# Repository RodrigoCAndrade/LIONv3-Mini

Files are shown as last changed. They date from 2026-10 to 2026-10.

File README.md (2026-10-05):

<div align="center">
  Rodrigo Andrade Logo
</div>

<h1 align="center">LIONv3-Mini Module</h1>

<p align="center">
    
    
    
    
    
</p>

<br>

<p align="center">
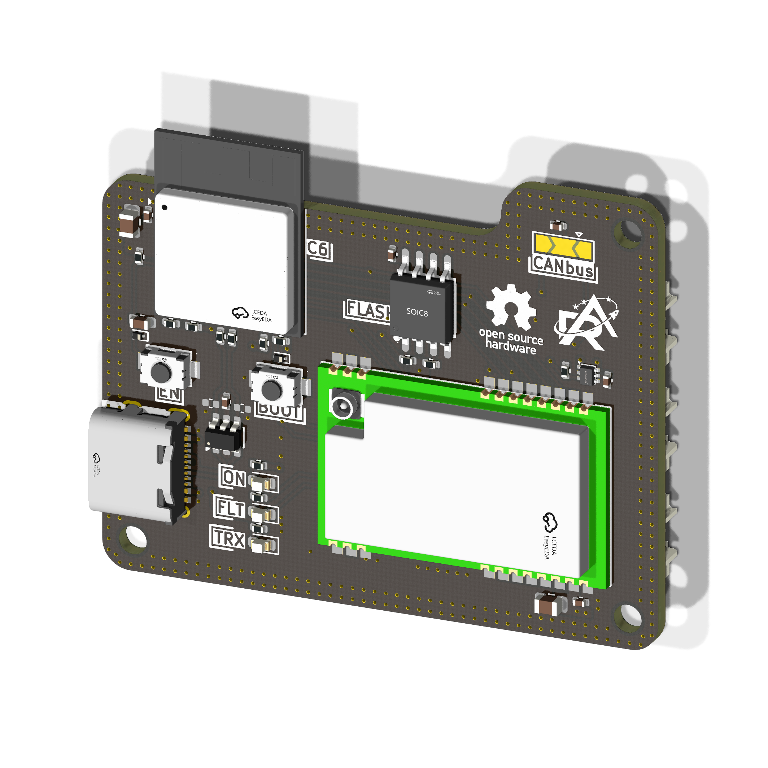
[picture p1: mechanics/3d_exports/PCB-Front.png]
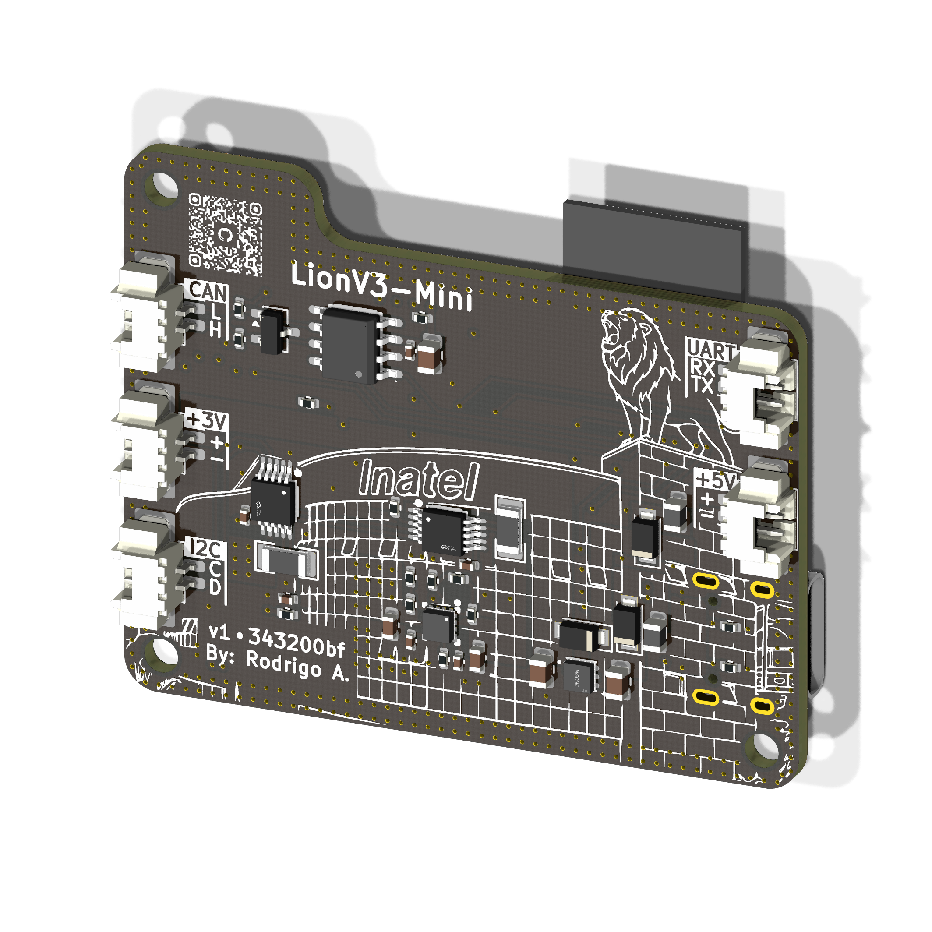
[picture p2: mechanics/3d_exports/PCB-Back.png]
    
</p>

## Overview

The LIONv3-Mini is a miniaturized version of the [LIONv3-R](https://github.com/RodrigoCAndrade/LIONv3-Mini), without an onboard LoRa PCB antenna. Built around the ESP32-C6 with 16 MB of external flash, it offers local connectivity over Wi-Fi, Zigbee and Thread, plus LoRa and LR-FHSS for reliable Direct-to-Satellite (DtS) or terrestrial uplinks from remote sites at higher device densities than conventional LoRa. It is a scalable platform for telemetry, global asset tracking and remote sensing.

## Repository Organization

* `docs`: Systems engineering documentation, including schematics, datasheets, requirements (SRD), interface control (ICD) and diagrams.
* `hardware`: Native KiCad project and manufacturing files.
* `mechanics`: 3D models, technical drawings, and physical integration constraints.
* `software`: Embedded firmware and support testing scripts.

## Releases

<table>
  <thead>
    <tr>
      <th>Render</th>
      <th>Hardware Revision</th>
      <th>Status</th>
      <th>Latest Release</th>
      <th>Date</th>
      <th>Datasheet</th>
      <th>BOM</th>
      <th>Manufacturing Info</th>
    </tr>
  </thead>
  <tbody>
    <tr>
      <td>board render</td>
      <td>LIONv3-Mini</td>
      <td>🚧 Development</td>
      <td><a href="#">-</a></td>
      <td>05-10-2026</td>
      <td><a href="#">PDF</a></td>
      <td><a href="hardware/Fabrication/BOM-LIONv3.csv">Available</a></td>
      <td><a href="hardware/Fabrication/GERBER-LIONv3.zip">Gerber</a></td>
    </tr>
  </tbody>
</table>

## Fabrication

This board is intended to be fabricated at [JLCPCB](https://jlcpcb.com/). The Gerber files, position files and BOM are available. For complete instructions, see the [Fabrication Guide](hardware/Fabrication/LIONv3-Mini%20Fabrication%20Guide.pdf). Please note that we do not guarantee the board will work, and any manufacturing issues are the user's responsibility. If you find an error or have suggestions for improvement, please do not hesitate to contribute.

## Contributing

We welcome contributions to this project! To ensure a smooth collaboration and maintain our engineering standards, please review our [Contribution Guidelines](CONTRIBUTING.md) before opening any issues, modifying the hardware design, or submitting pull requests.

## References

This board was developed from scratch, but draws on the earlier LIONv1 and LIONv2 designed by [Diego Anestor Coutinho](https://github.com/DIEGOVZK) and [Arielli Ajudarte](https://github.com/ari-aju). The v3 introduces several improvements:

- Dedicated low-power MCU on board
- LR-FHSS support and a more capable LoRa transceiver, covering both sub-GHz and S-band
- External flash for store-and-forward applications
- More compact form factor

<p align="center">
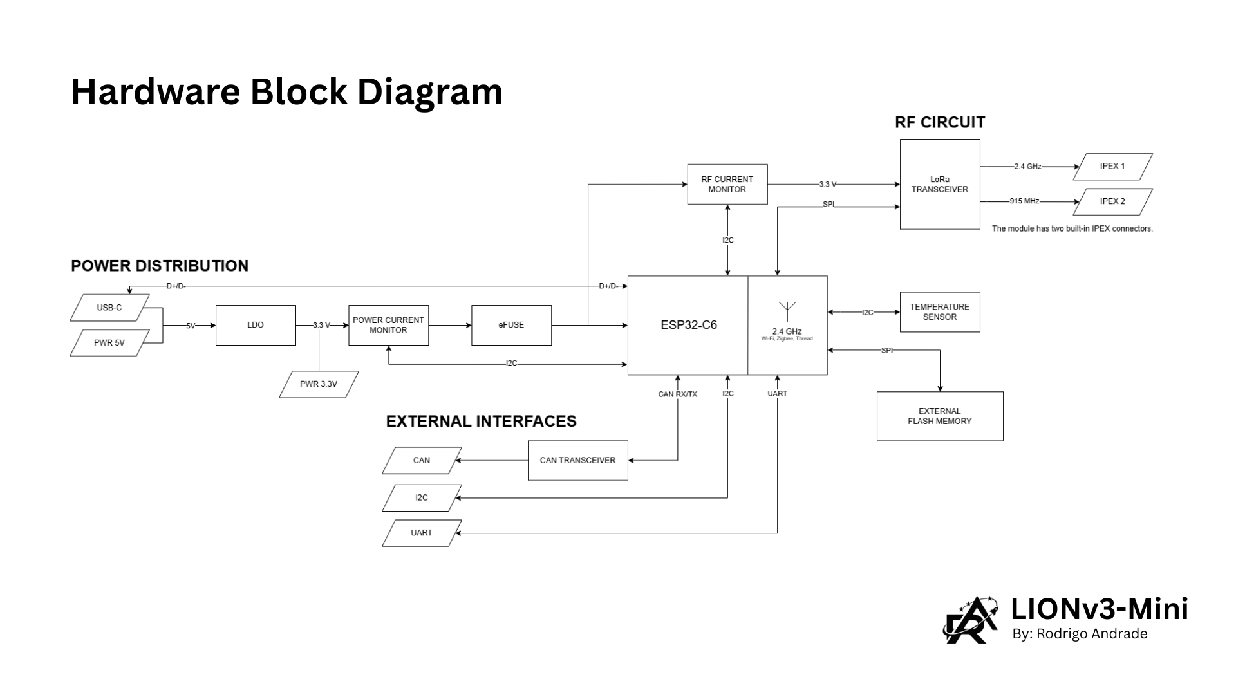
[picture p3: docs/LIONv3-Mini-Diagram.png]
    
</p>

## License

This project utilizes a dual-licensing approach to maximize flexibility and adoption:

* **Hardware:** The hardware designs and schematics are licensed under the permissive **[CERN-OHL-P-2.0](hardware/LICENSE)** open-hardware license. You are entirely free to use, modify, distribute, and commercialize the design without any copyleft obligations to share your derived works under the same terms.
* **Software:** All embedded firmware and utility scripts are licensed under the **[MIT License](software/LICENSE)**. You are free to use, modify, and distribute the code without restriction, provided the original copyright notice and permission notice are included.

## Acknowledgments

This work was carried out at the National Institute of Telecommunications (Inatel) with the support of three research laboratories. The EMBRAPII Inatel Competence Center for 5G and 6G Networks [(xGMobile)](https://inatel.br/xgmobile/) supported this project through its Talent Development Program (PFT xGMobile), alongside the Radio & Communication Laboratory [(RadioCom Lab)](https://inatel.br/radiocomlab/) and the Wireless and Artificial Intelligence Laboratory [(WAI Lab)](https://inatel.br/wailab/). Many thanks to the researchers and staff of all three laboratories for their help and for the infrastructure that made the LIONv3-Mini possible.

<p align="center">
  Funding
</p>

<p align="center">
  <sub>Built with ❤️ by <a href="https://rodrigoandrade.com">Rodrigo de Carvalho Andrade</a></sub>
</p>

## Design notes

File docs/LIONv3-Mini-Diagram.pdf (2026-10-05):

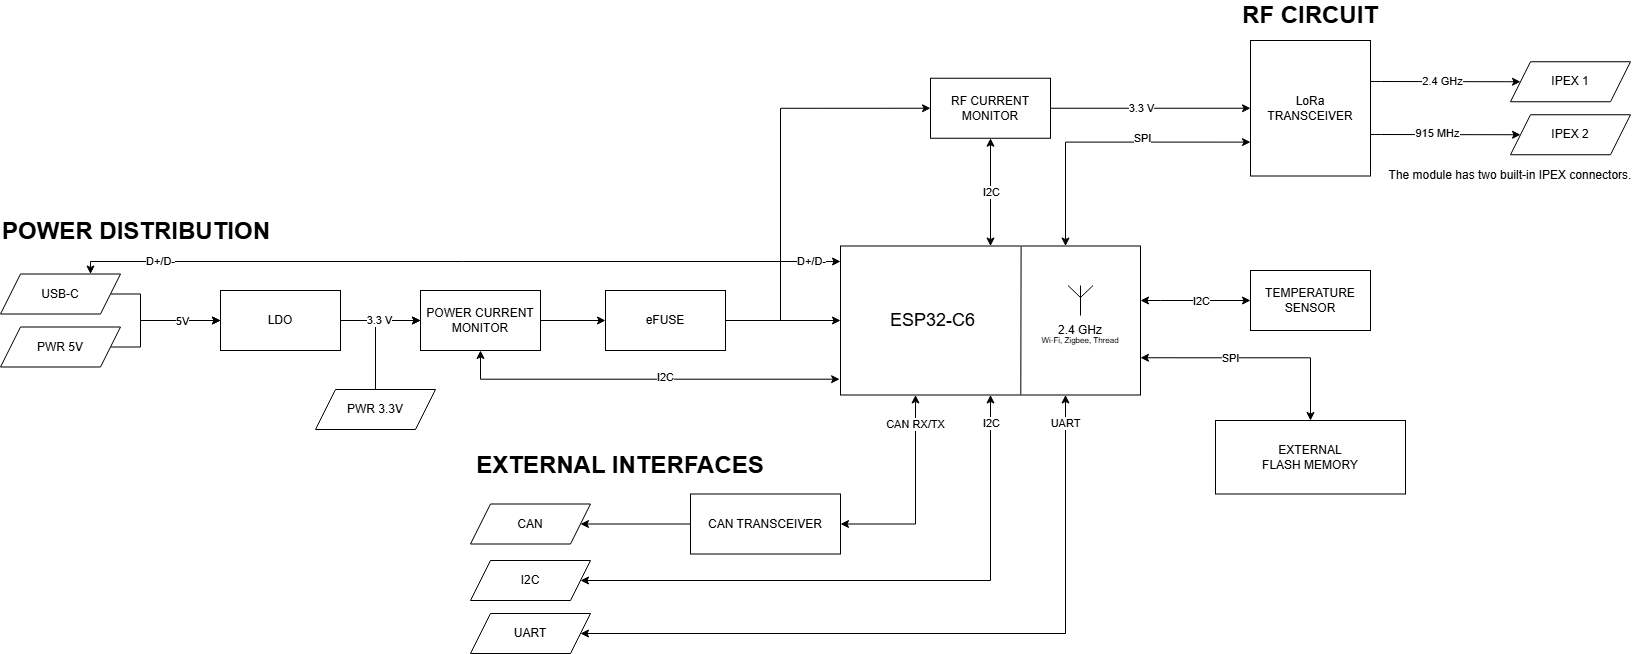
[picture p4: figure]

LIONv3-Mini

By: Rodrigo Andrade

Hardware Block Diagram

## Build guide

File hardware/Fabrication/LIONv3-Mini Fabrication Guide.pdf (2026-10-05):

# LIONv3-Mini Fabrication Guide

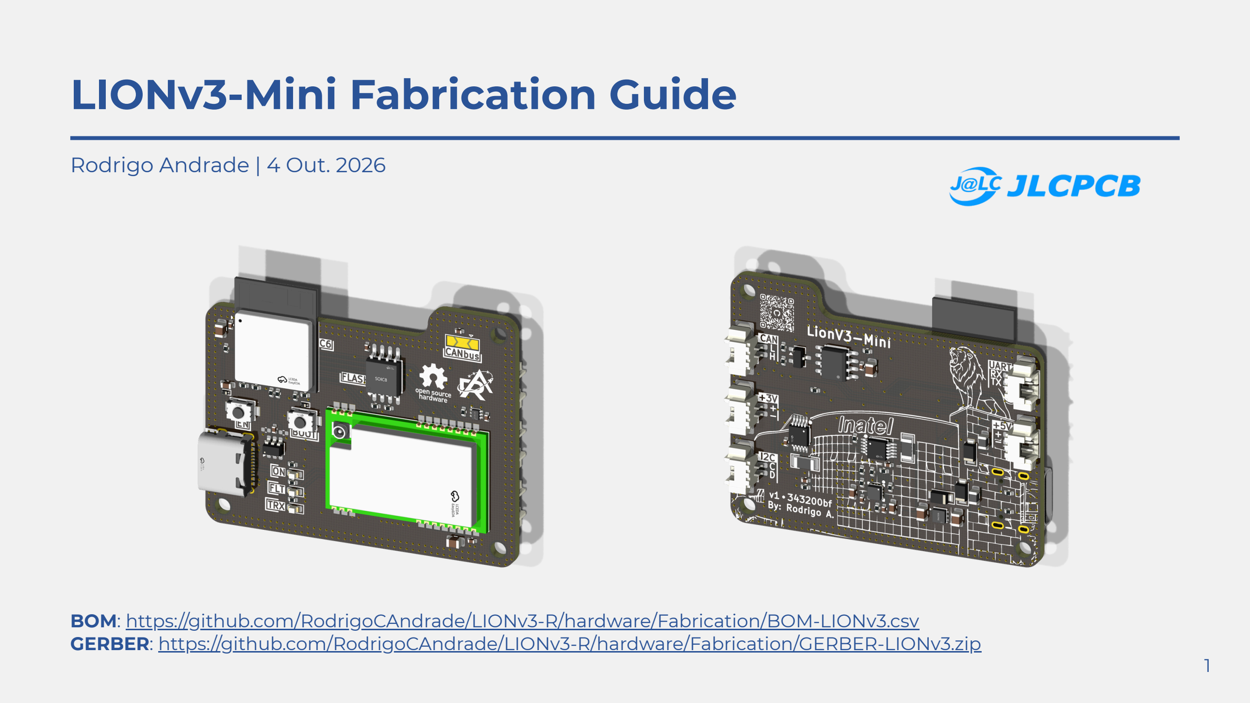
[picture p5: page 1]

Rodrigo Andrade | 4 Out. 2026

BOM: https://github.com/RodrigoCAndrade/LIONv3-R/hardware/Fabrication/BOM-LIONv3.csv GERBER: https://github.com/RodrigoCAndrade/LIONv3-R/hardware/Fabrication/GERBER-LIONv3.zip

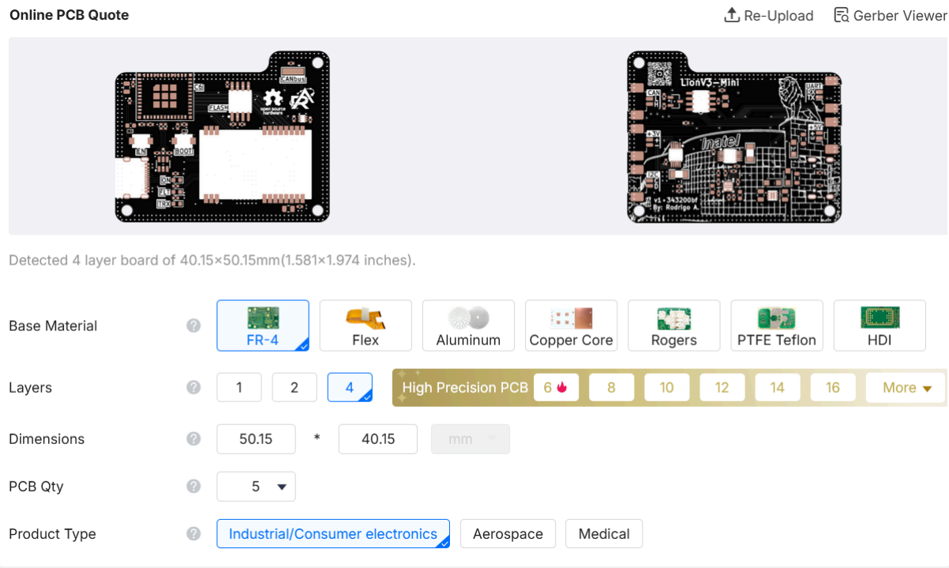
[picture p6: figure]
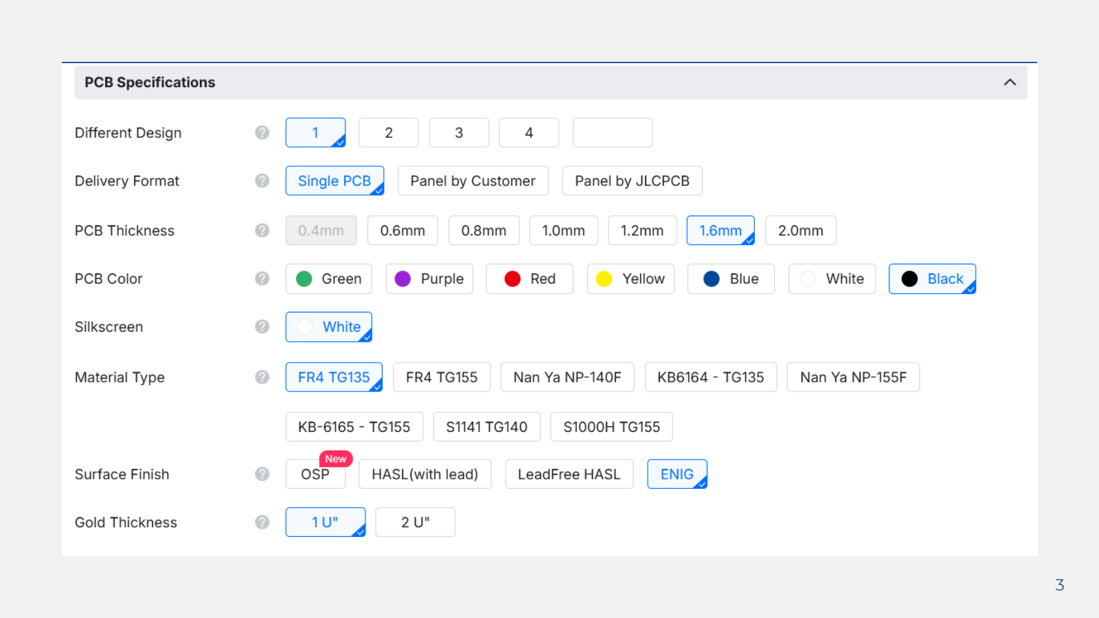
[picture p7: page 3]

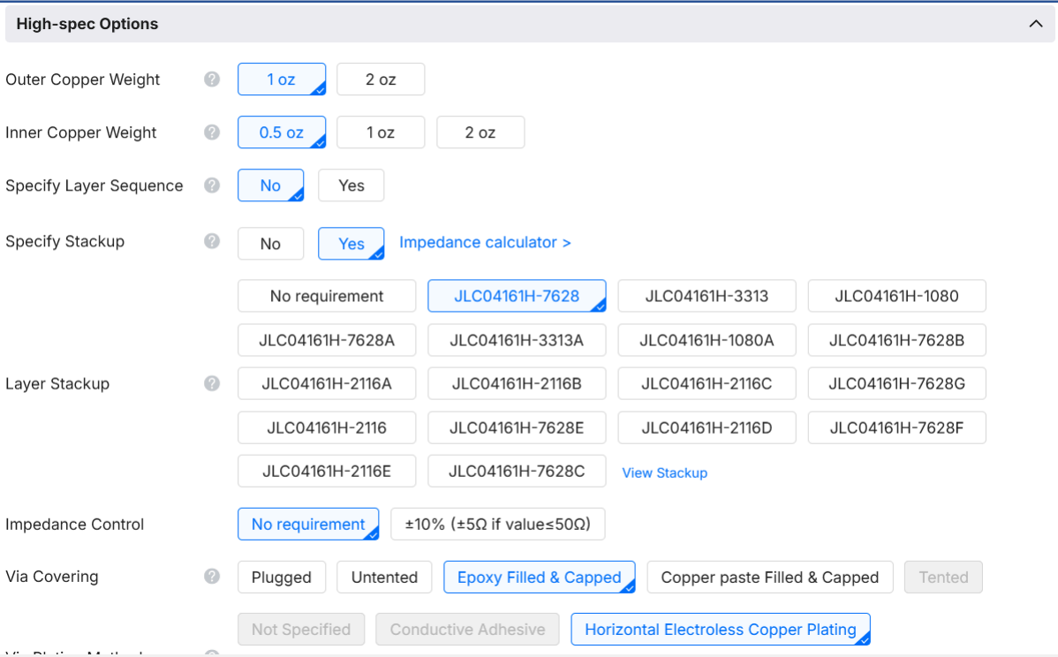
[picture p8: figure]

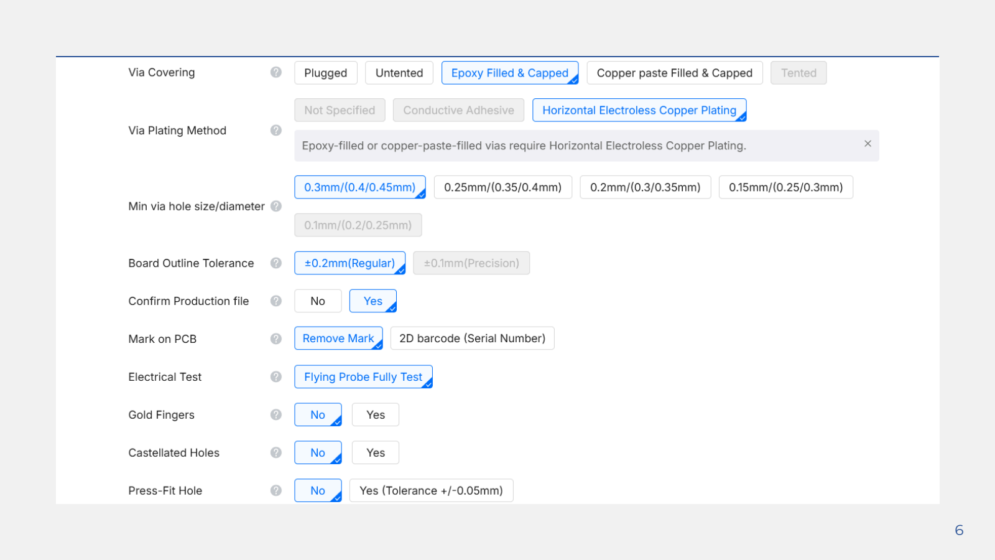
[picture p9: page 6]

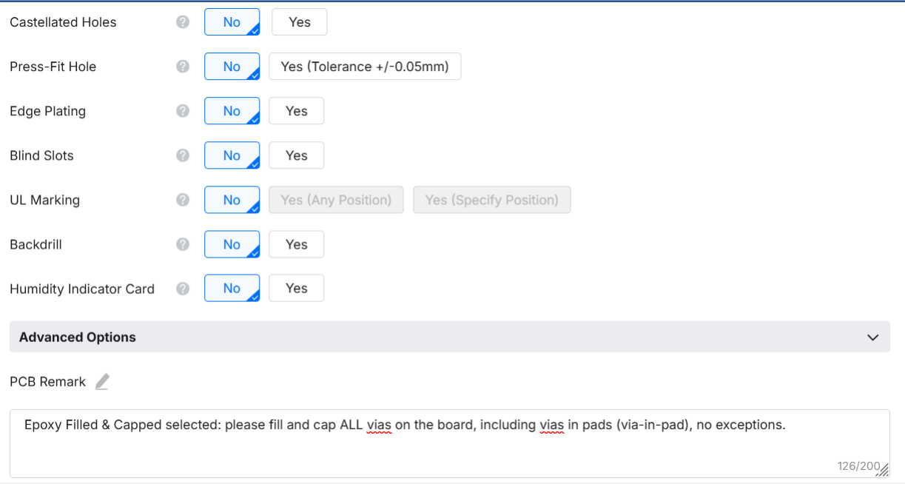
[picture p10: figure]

Please add the following remark on the PCB:
“Please add the board version to the stencil for easier identification. The following would be good: "LIONv3-MINI (rev1.0) • 343200bf”

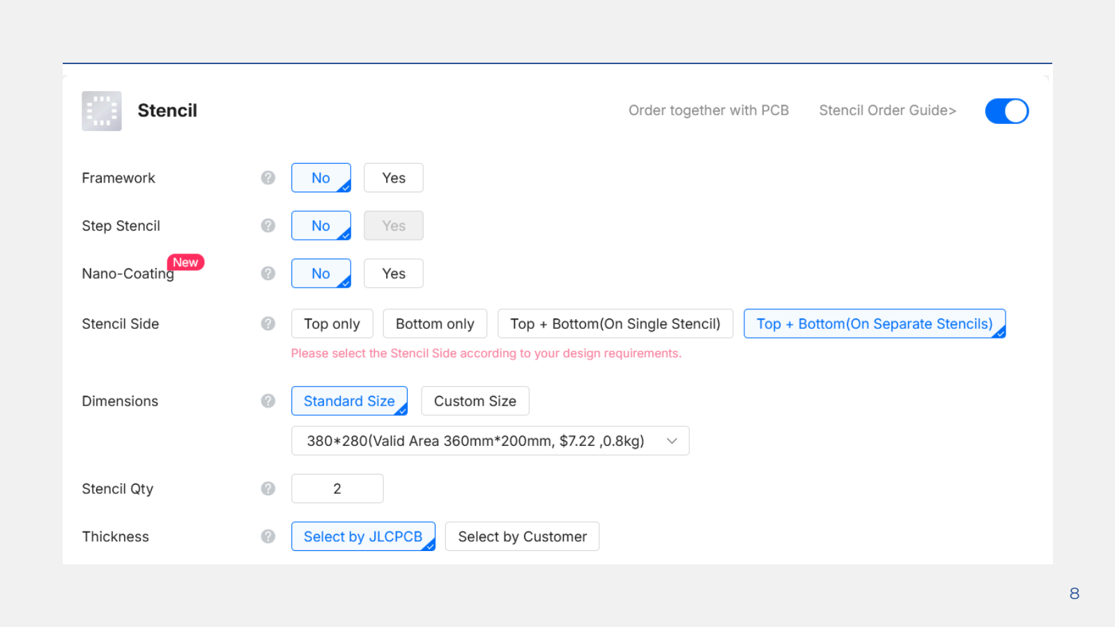
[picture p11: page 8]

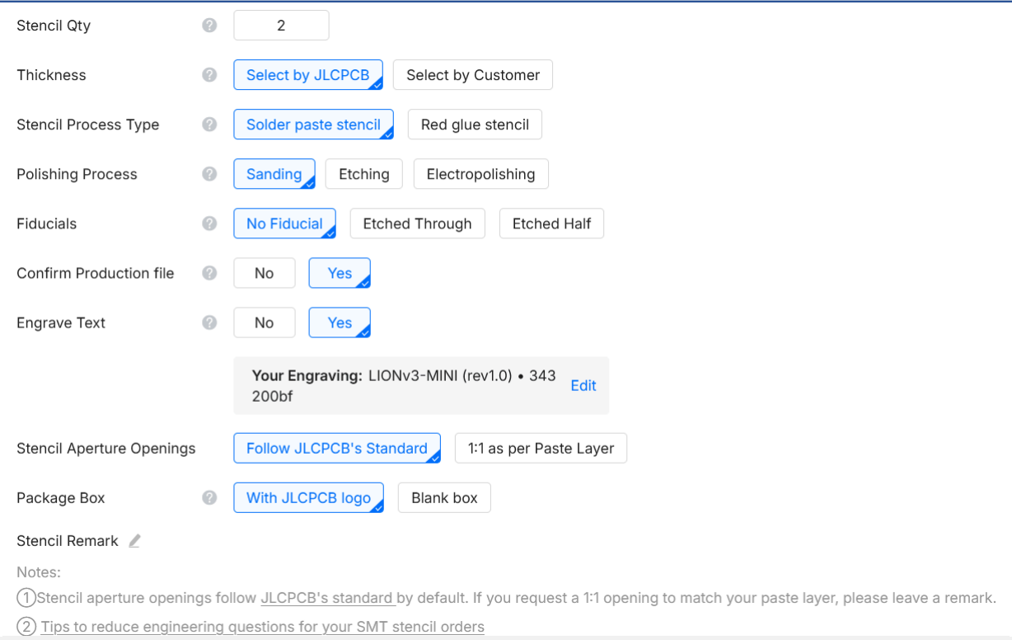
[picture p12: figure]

Please add the board version to the stencil for easier identification. The following would be good: "LIONv3-MINI (rev1.0) • 343200bf

Parameter | Specification
Base Material | FR4
Layers | 4
PCB Color | Black
Surface Finish | ENIG
Specify Stackup | Yes (JLC04161H-7628)

# PCB Fabrication Checklist

Parameter | Specification
Impedance Control | No Requirement
Via Covering | Epoxy Filled & Capped
Confirm Production file | Yes
PCB Remark | Fill and cap ALL vias on the board

Parameter | Specification
Stencil Side | Top + Bottom (On Separate Stencils)
Confirm Production file | Yes
Engrave Text | Yes (LIONv3-MINI (rev1.0) • 343200bf)

# Stencil Fabrication Checklist

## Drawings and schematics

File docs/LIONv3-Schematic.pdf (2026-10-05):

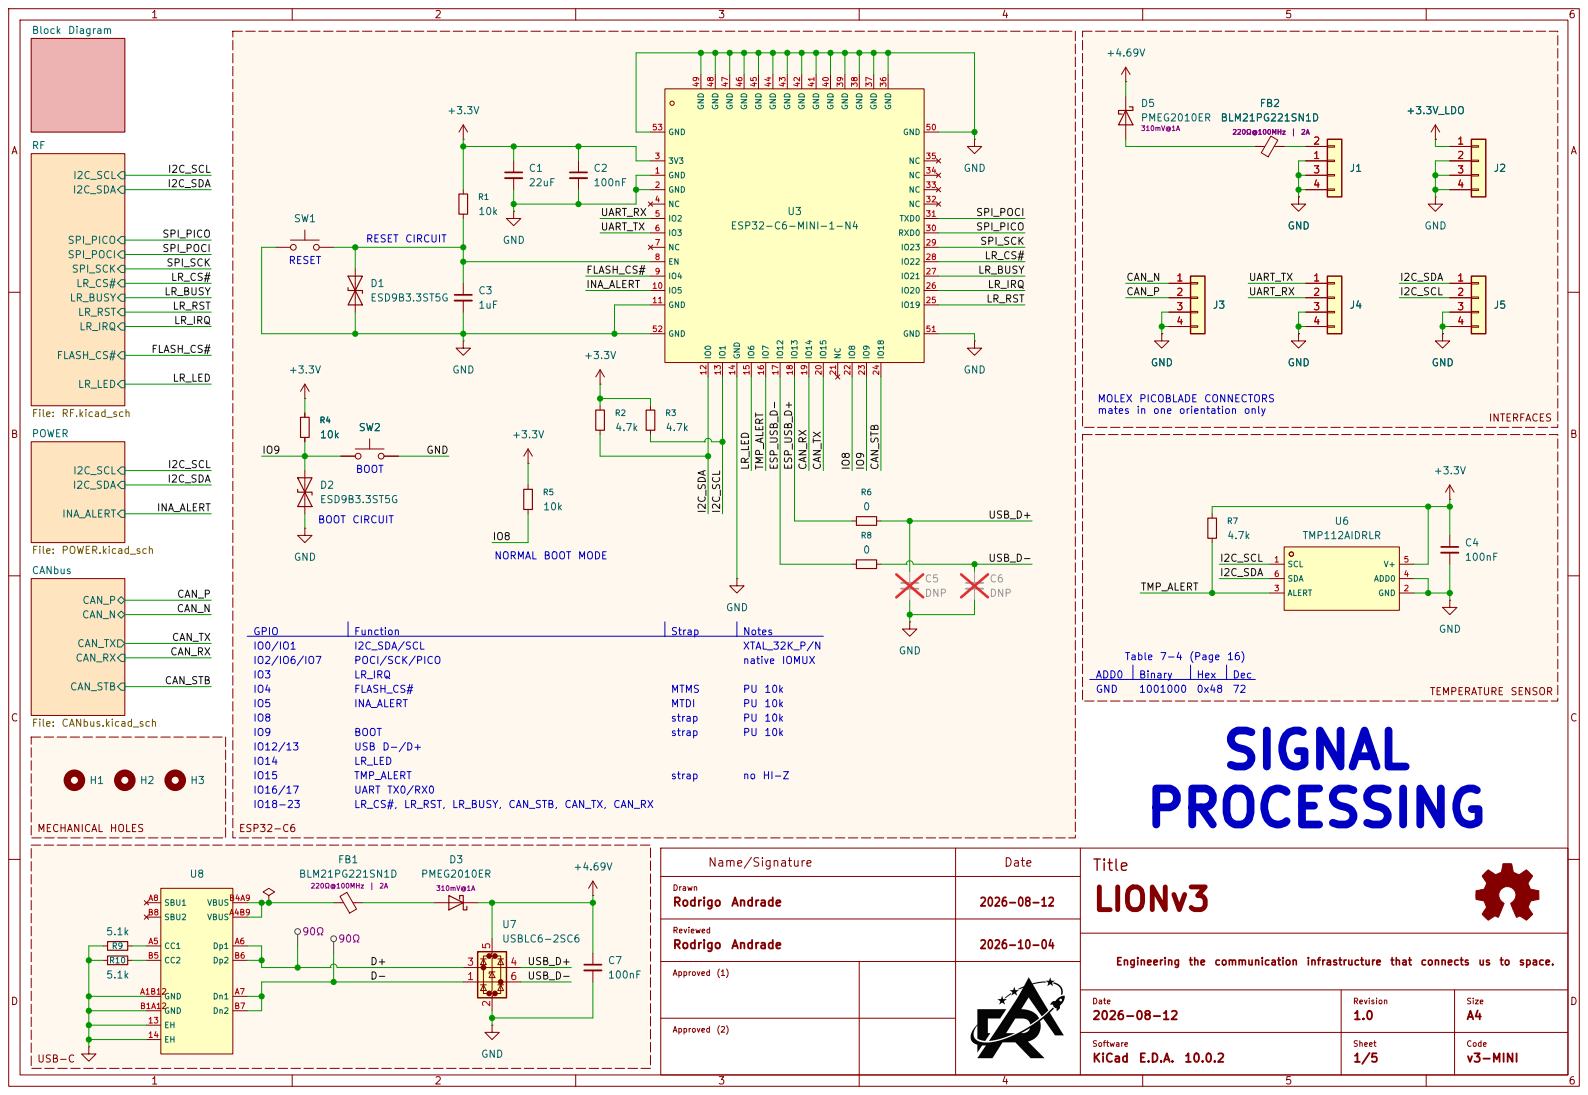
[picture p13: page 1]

CAN_P
Engineering the communication infrastructure that connects us to space. Code v3-MINI CAN_N

Name/Signature | Date | LIONv3 | D Title

Drawn Reviewed Rodrigo Andrade | 2026-08-12

Rodrigo Andrade | 2026-10-04

Approved (1) Approved (2)

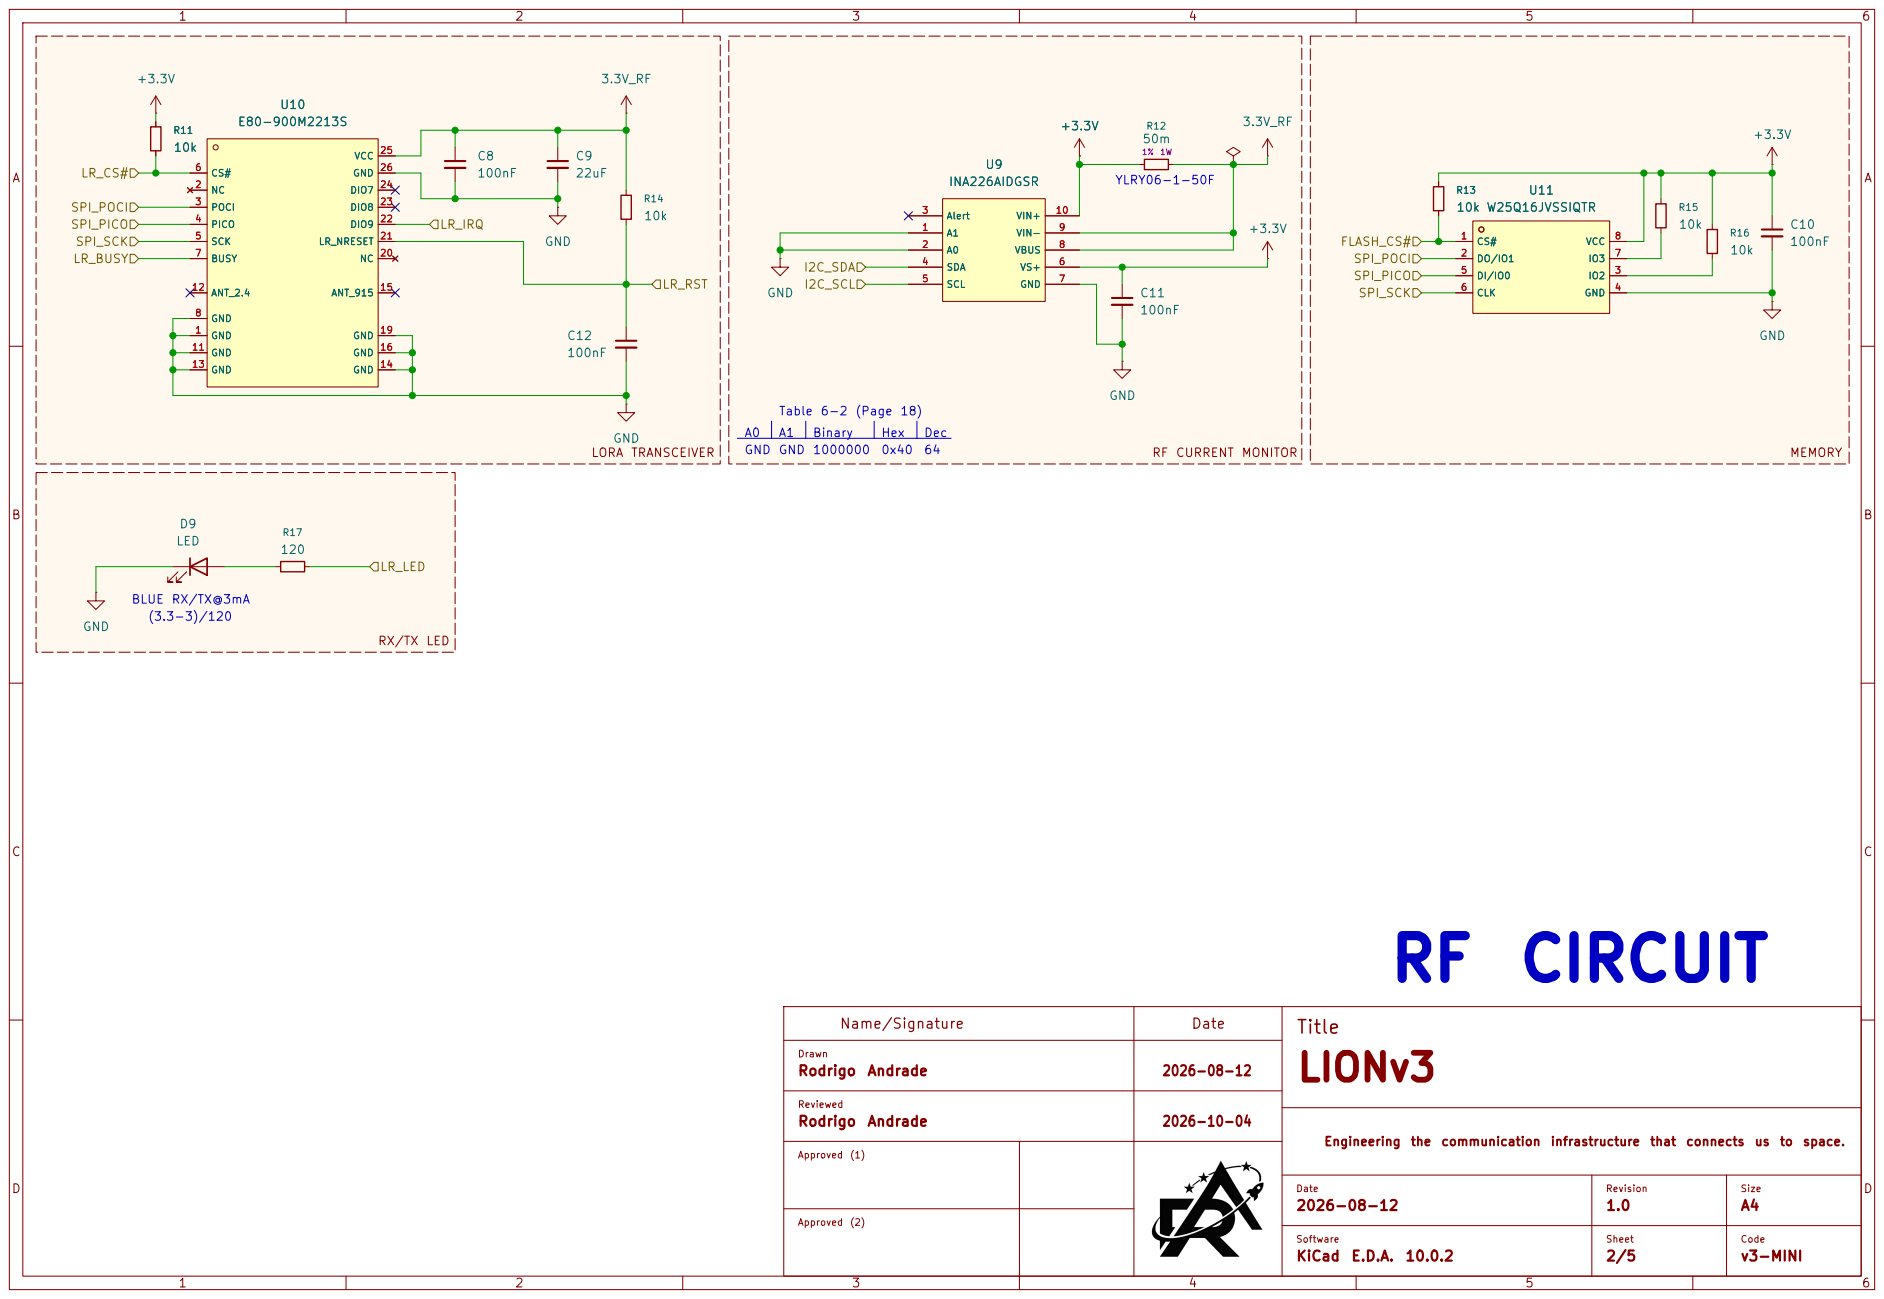
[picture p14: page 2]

Name/Signature | Date | LIONv3 | D Title

Drawn Reviewed Rodrigo Andrade | 2026-08-12

Rodrigo Andrade | 2026-10-04

Engineering the communication infrastructure that connects us to space. Code v3-MINI

Approved (1) Approved (2)

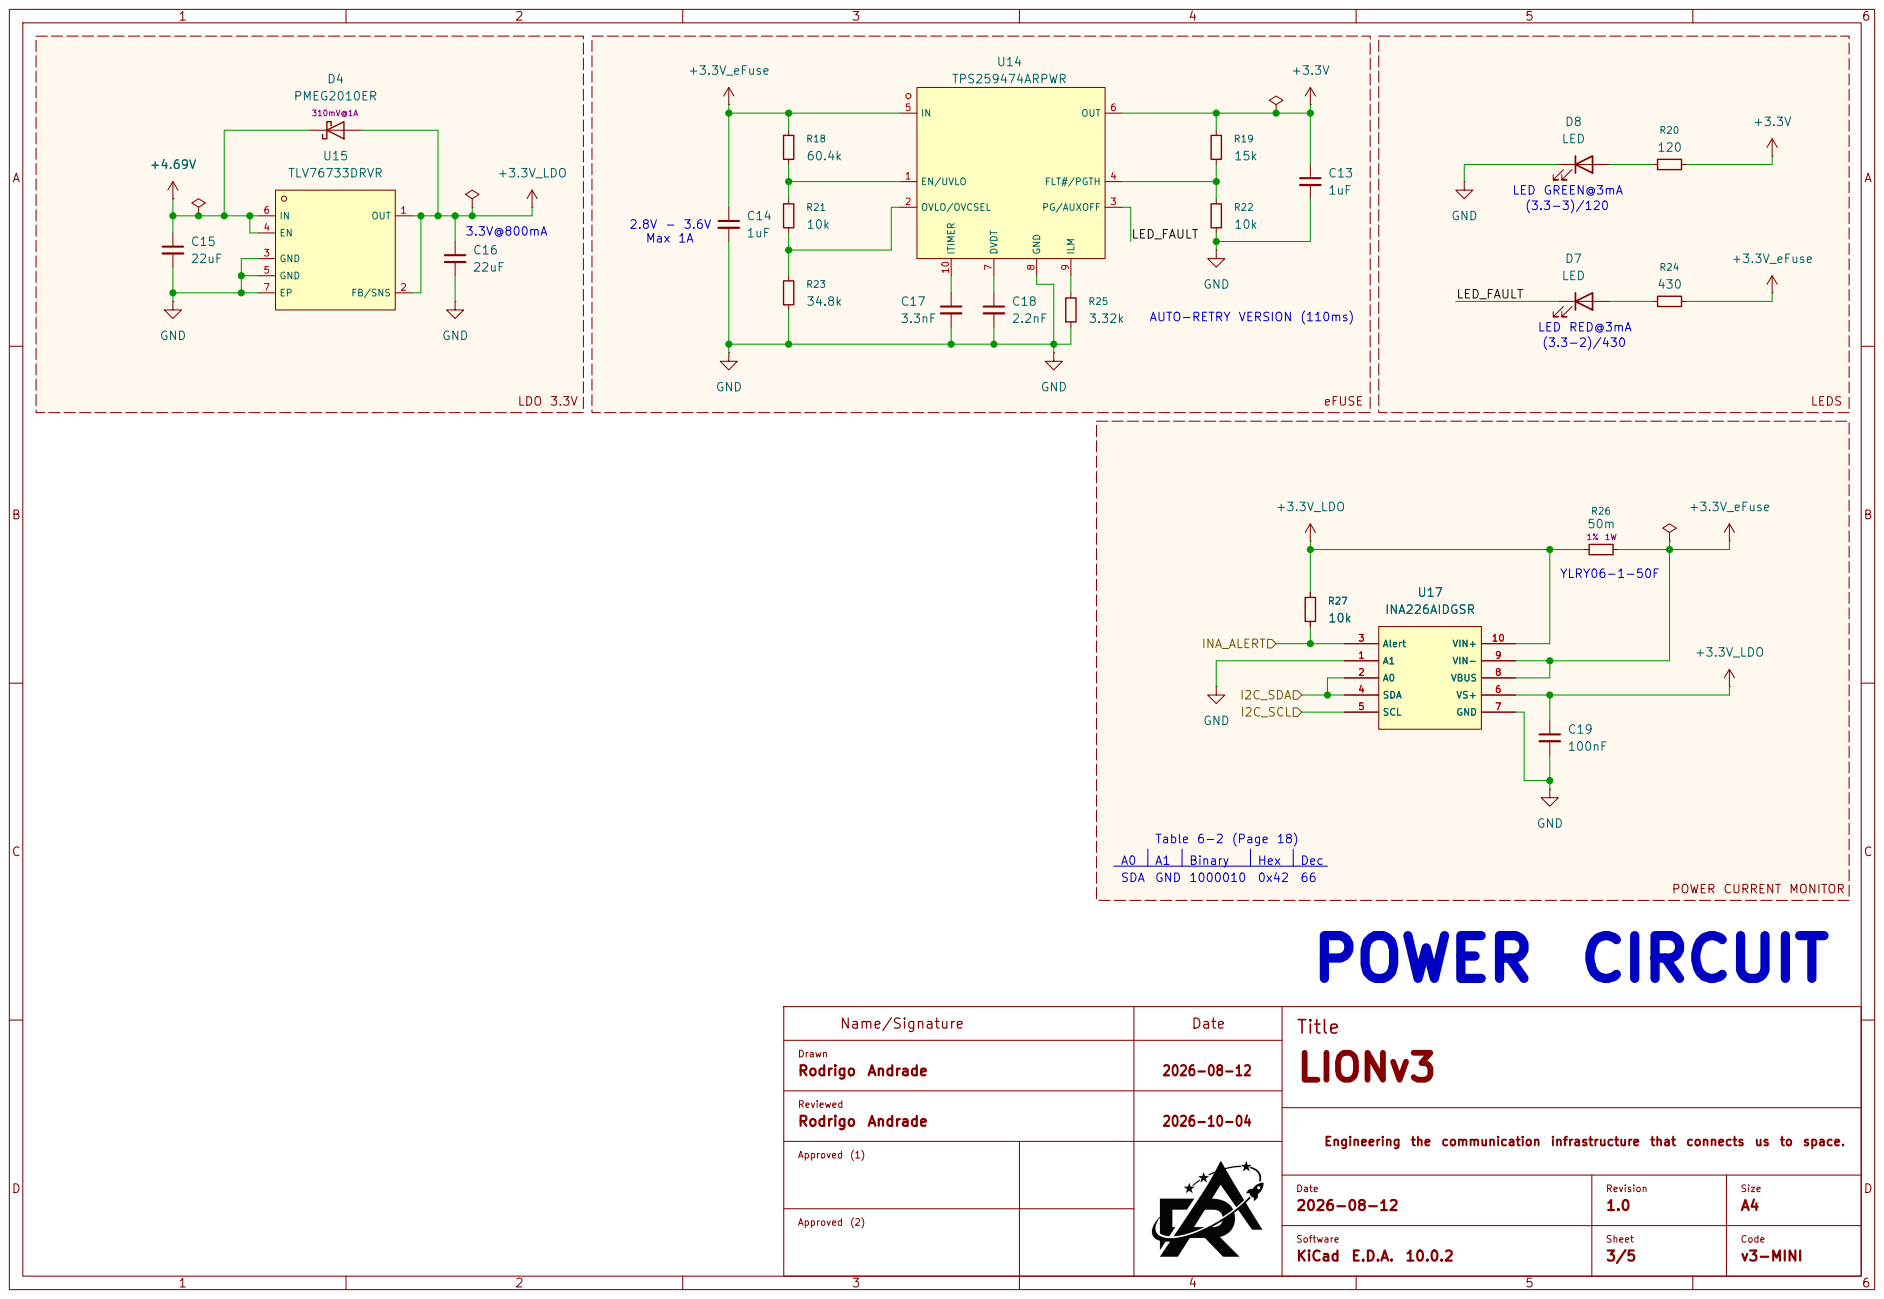
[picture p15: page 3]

Name/Signature | Date | LIONv3 | D Title

Drawn Reviewed Rodrigo Andrade | 2026-08-12

Rodrigo Andrade | 2026-10-04

Engineering the communication infrastructure that connects us to space. Code v3-MINI

Approved (1) Approved (2)

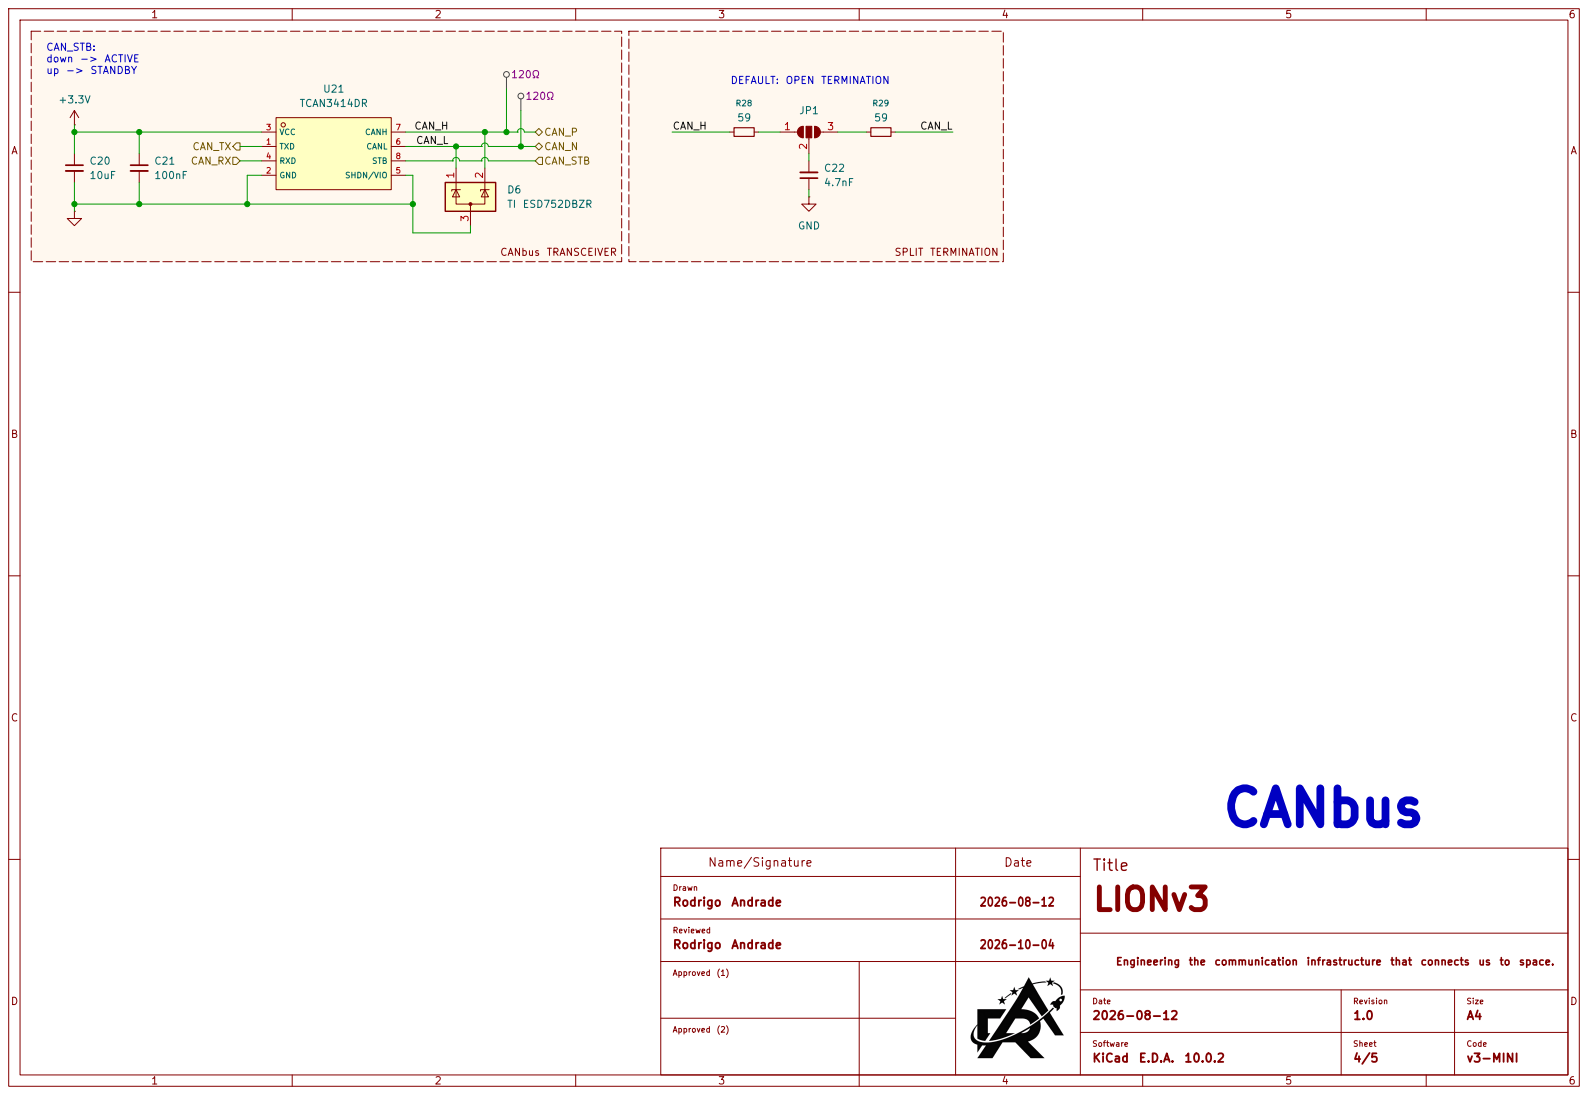
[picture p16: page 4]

CAN_STB: down -> ACTIVE | DEFAULT: OPEN TERMINATION R29 59 JP1 GND

VCC 3 RXD 4 TXD 1 GND 2

Name/Signature | Date | LIONv3 | D Title

Drawn Reviewed Rodrigo Andrade | 2026-08-12

Rodrigo Andrade | 2026-10-04

Engineering the communication infrastructure that connects us to space. Code v3-MINI

Approved (1) Approved (2)

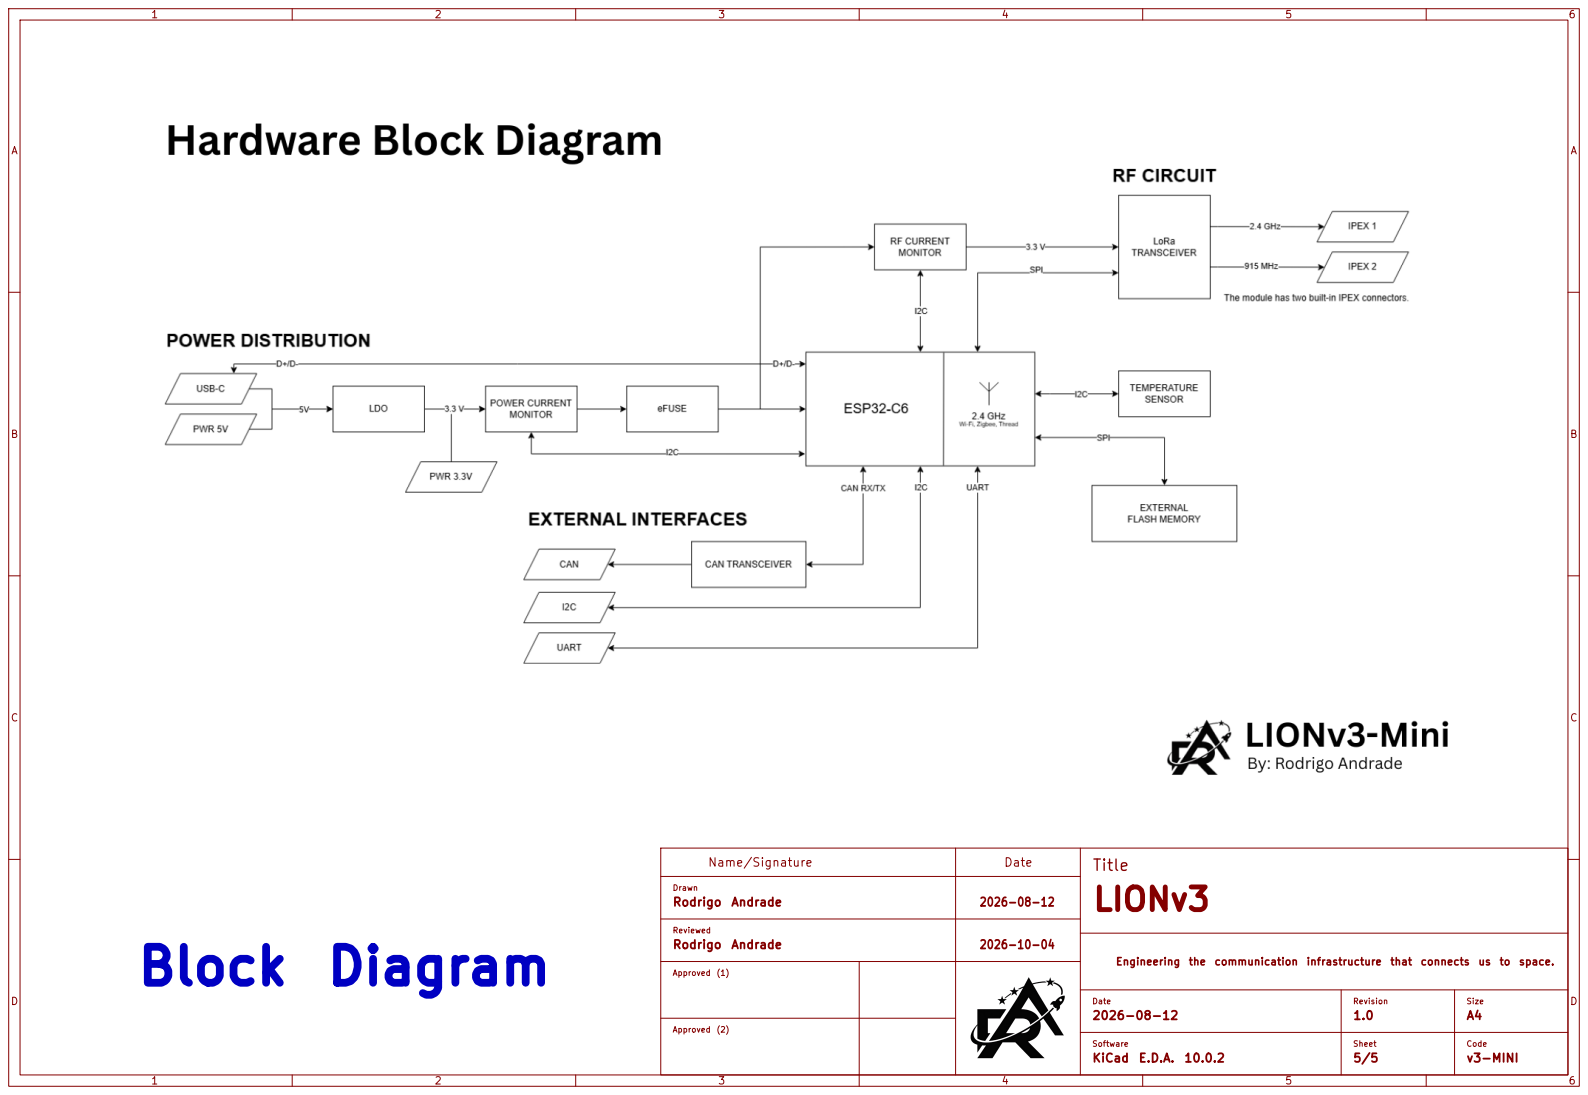
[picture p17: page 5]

Name/Signature | Date | LIONv3 | D Title

Drawn Reviewed Rodrigo Andrade | 2026-08-12

Rodrigo Andrade | 2026-10-04

Engineering the communication infrastructure that connects us to space. Code v3-MINI

Approved (1) Approved (2)

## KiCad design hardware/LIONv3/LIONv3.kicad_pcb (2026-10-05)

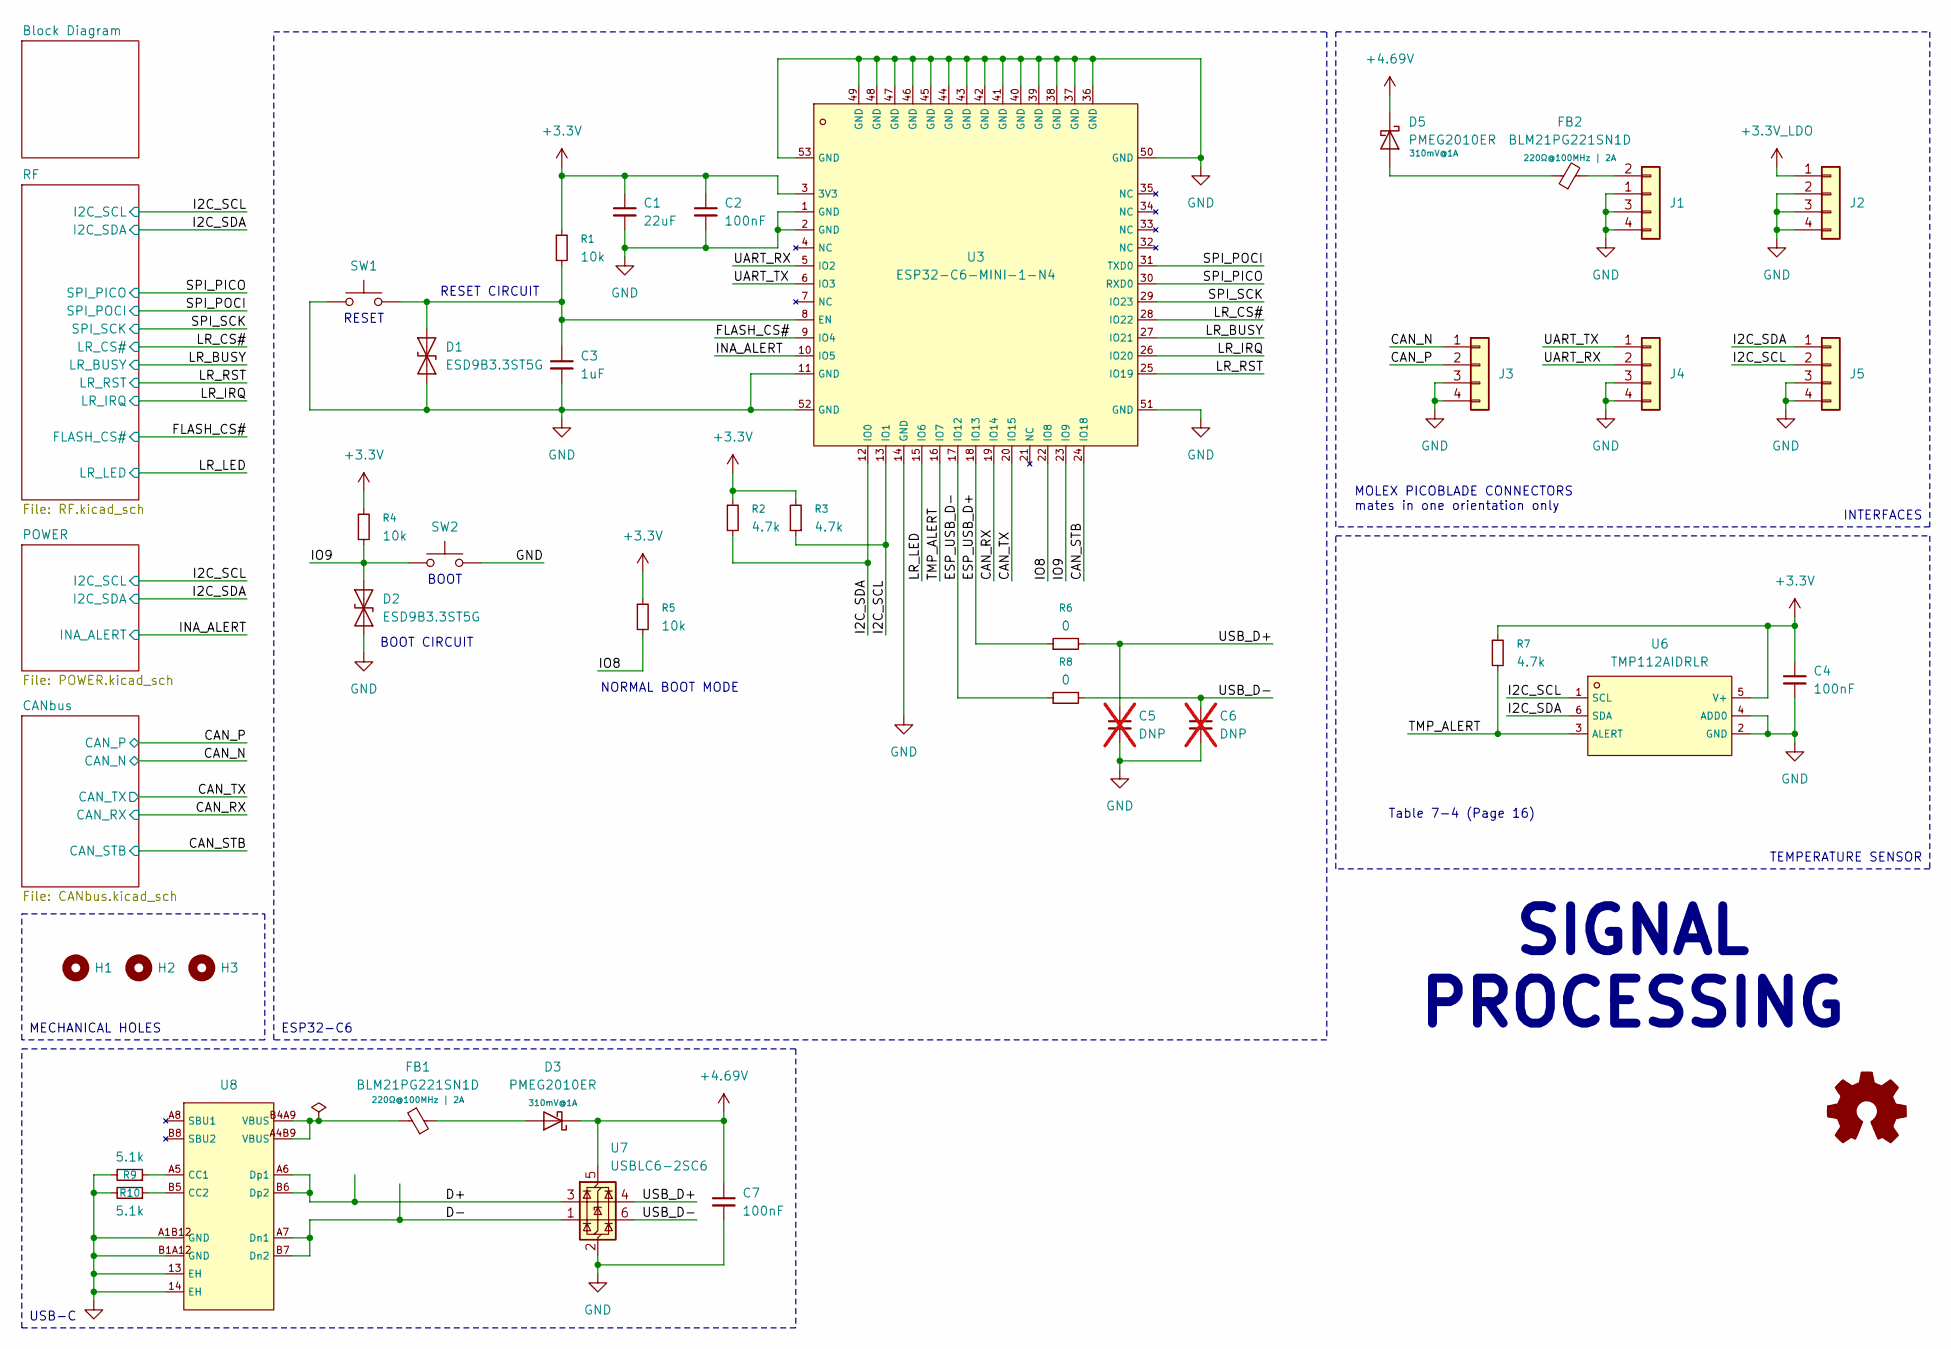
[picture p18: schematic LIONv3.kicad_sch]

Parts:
C1: 22uF; C_0805_2012Metric; LCSC C45783
C2, C4, C7: 100nF; C_0402_1005Metric; LCSC C307331
C3: 1uF; C_0603_1608Metric; LCSC C15849
C5, C6: DNP; C_0402_1005Metric; not fitted
D1, D2: ESD9B3.3ST5G; D_SOD-923; LCSC C96512
D3, D5: PMEG2010ER; Nexperia_CFP3_SOD-123W; Rating 310mV@1A; LCSC C82288
FB1, FB2: BLM21PG221SN1D; L_0805_2012Metric; Rating 220Ω@100MHz | 2A; LCSC C85840
H1, H2, H3: MountingHole_Pad; MountingHole_2.5mm
J1, J2, J3, J4, J5: 532610271; Molex_PicoBlade_53261-0271_1x02-1MP_P1.25mm_Horizontal; LCSC C177225
R1, R4, R5: 10k; R_0402_1005Metric; LCSC C25744
R2, R3, R7: 4.7k; R_0402_1005Metric; LCSC C25900
R6, R8: 0; R_0402_1005Metric; LCSC C17168
R9, R10: 5.1k; R_0402_1005Metric; LCSC C25905
S1: Logo_Open_Hardware_Small; OSHW-Logo2_14.6x12mm_SilkScreen
SW1, SW2: KEY-SMD_L3.9-W3.0-LS5.0; LCSC C5373431
U3: ESP32-C6-MINI-1-N4; ESP32-C6-MINI-1; LCSC C5736265
U6: TMP112AIDRLR; SOT-563_L1.6-W1.2-P0.50-LS1.6-BR; LCSC C28927
U7: USBLC6-2SC6; SOT-23-6; LCSC C7519
U8: TYPE-C_16PIN_2MD(073); USB-C-SMD_TYPE-C-16PIN-2MD-073; LCSC C2765186

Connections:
+3.3V: C1.1, C2.1, C4.1, R1.1, R2.1, R3.2, R4.1, R5.1, R7.1, U3.3 (3V3), U6.5 (V+); also elsewhere on the board
+3.3V_LDO: J2.1; also elsewhere on the board
+4.69V: C7.1, D3.1 (K), D5.1 (K), U7.5 (VBUS); also elsewhere on the board
/CAN_N: J3.1; also elsewhere on the board
/CAN_P: J3.2; also elsewhere on the board
/CAN_RX: U3.19 (IO14); also elsewhere on the board
/CAN_STB: U3.24 (IO18); also elsewhere on the board
/CAN_TX: U3.20 (IO15); also elsewhere on the board
/D+: U7.3 (I/O2), U8.A6 (Dp1), U8.B6 (Dp2)
/D-: U7.1 (I/O1), U8.A7 (Dn1), U8.B7 (Dn2)
/ESP_USB_D+: R6.1, U3.18 (IO13)
/ESP_USB_D-: R8.1, U3.17 (IO12)
/FLASH_CS#: U3.9 (IO4); also elsewhere on the board
/I2C_SCL: J5.2, R3.1, U3.13 (IO1), U6.1 (SCL); also elsewhere on the board
/I2C_SDA: J5.1, R2.2, U3.12 (IO0), U6.6 (SDA); also elsewhere on the board
/INA_ALERT: U3.10 (IO5); also elsewhere on the board
/IO8: R5.2, U3.22 (IO8)
/IO9: D2.2 (A2), R4.2, SW2.1, U3.23 (IO9)
/LR_BUSY: U3.27 (IO21); also elsewhere on the board
/LR_CS#: U3.28 (IO22); also elsewhere on the board
/LR_IRQ: U3.26 (IO20); also elsewhere on the board
/LR_LED: U3.15 (IO6); also elsewhere on the board
/LR_RST: U3.25 (IO19); also elsewhere on the board
/SPI_PICO: U3.30 (RXD0); also elsewhere on the board
/SPI_POCI: U3.31 (TXD0); also elsewhere on the board
/SPI_SCK: U3.29 (IO23); also elsewhere on the board
/TMP_ALERT: R7.2, U3.16 (IO7), U6.3 (ALERT)
/UART_RX: J4.2, U3.5 (IO2)
/UART_TX: J4.1, U3.6 (IO3)
/USB_D+: C5.1, R6.2, U7.4 (I/O2)
/USB_D-: C6.1, R8.2, U7.6 (I/O1)
GND: C1.2, C2.2, C3.2, C4.2, C5.2, C6.2, C7.2, D1.1 (A1), D2.1 (A1), J1.1, J1.3, J1.4, J2.2, J2.3, J2.4, J3.3, J3.4, J4.3, J4.4, J5.3, J5.4, R9.2, R10.2, SW1.1, SW2.2, U3.1 (GND), U3.2 (GND), U3.11 (GND), U3.14 (GND), U3.36 (GND), U3.37 (GND), U3.38 (GND), U3.39 (GND), U3.40 (GND), U3.41 (GND), U3.42 (GND), U3.43 (GND), U3.44 (GND), U3.45 (GND), U3.46 (GND), U3.47 (GND), U3.48 (GND), U3.49 (GND), U3.50 (GND), U3.51 (GND), U3.52 (GND), U3.53 (GND), U6.2 (GND), U6.4 (ADD0), U7.2 (GND), U8.13 (EH), U8.14 (EH), U8.A1B12 (GND), U8.B1A12 (GND); also elsewhere on the board
unnamed: C3.1, D1.2 (A2), R1.2, SW1.2, U3.8 (EN)
unnamed: D3.2 (A), FB1.1
unnamed: D5.2 (A), FB2.1
unnamed: FB1.2, U8.A4B9 (VBUS), U8.B4A9 (VBUS)
unnamed: FB2.2, J1.2
unnamed: R9.1, U8.A5 (CC1)
unnamed: R10.1, U8.B5 (CC2)

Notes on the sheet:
Table 7-4 (Page 16)
MOLEX PICOBLADE CONNECTORS mates in one orientation only
BOOT CIRCUIT
BOOT
SIGNAL PROCESSING
RESET CIRCUIT
NORMAL BOOT MODE
RESET
MECHANICAL HOLES
TEMPERATURE SENSOR
INTERFACES
ESP32-C6
USB-C

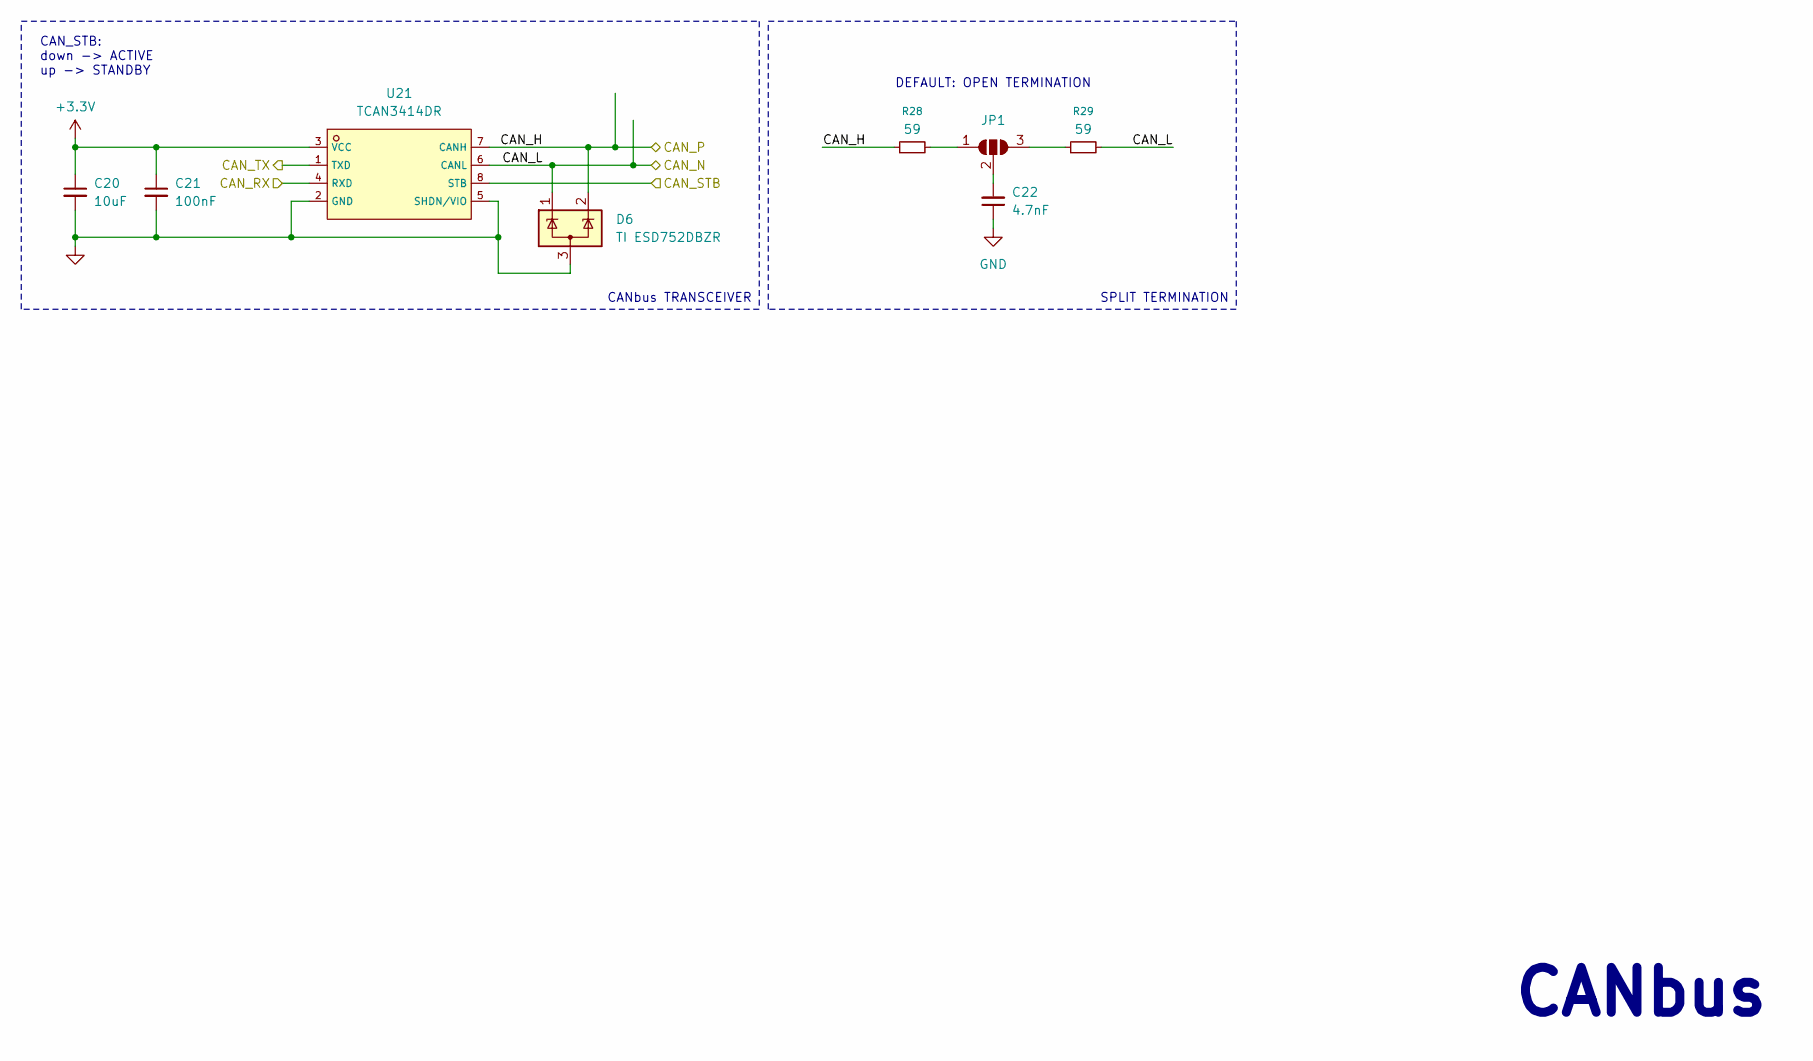
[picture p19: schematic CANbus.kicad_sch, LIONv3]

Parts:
C20: 10uF; C_0805_2012Metric; LCSC C440198
C21: 100nF; C_0402_1005Metric; LCSC C307331
C22: 4.7nF; C_0402_1005Metric; LCSC C1538
D6: TI ESD752DBZR; SOT-23-3; LCSC C20345397
JP1: SolderJumper_3_Open; SolderJumper-3_P2.0mm_Open_TrianglePad1.0x1.5mm
R28, R29: 59; R_0402_1005Metric; LCSC C227152
U21: TCAN3414DR; SOIC-8_L4.9-W3.9-P1.27-LS6.0-BL; LCSC C22396693

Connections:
+3.3V: C20.1, C21.1, U21.3 (VCC); also elsewhere on the board
/CAN_N: D6.1 (K), R29.2, U21.6 (CANL); also elsewhere on the board
/CAN_P: D6.2 (K), R28.1, U21.7 (CANH); also elsewhere on the board
/CAN_RX: U21.4 (RXD); also elsewhere on the board
/CAN_STB: U21.8 (STB); also elsewhere on the board
/CAN_TX: U21.1 (TXD); also elsewhere on the board
GND: C20.2, C21.2, C22.1, D6.3 (A), U21.2 (GND), U21.5 (SHDN/VIO); also elsewhere on the board
unnamed: JP1.1 (A), R28.2
unnamed: JP1.3 (B), R29.1
unnamed: C22.2, JP1.2 (C)

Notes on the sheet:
CAN_STB: down -> ACTIVE up -> STANDBY
CANbus
DEFAULT: OPEN TERMINATION
CANbus TRANSCEIVER
SPLIT TERMINATION

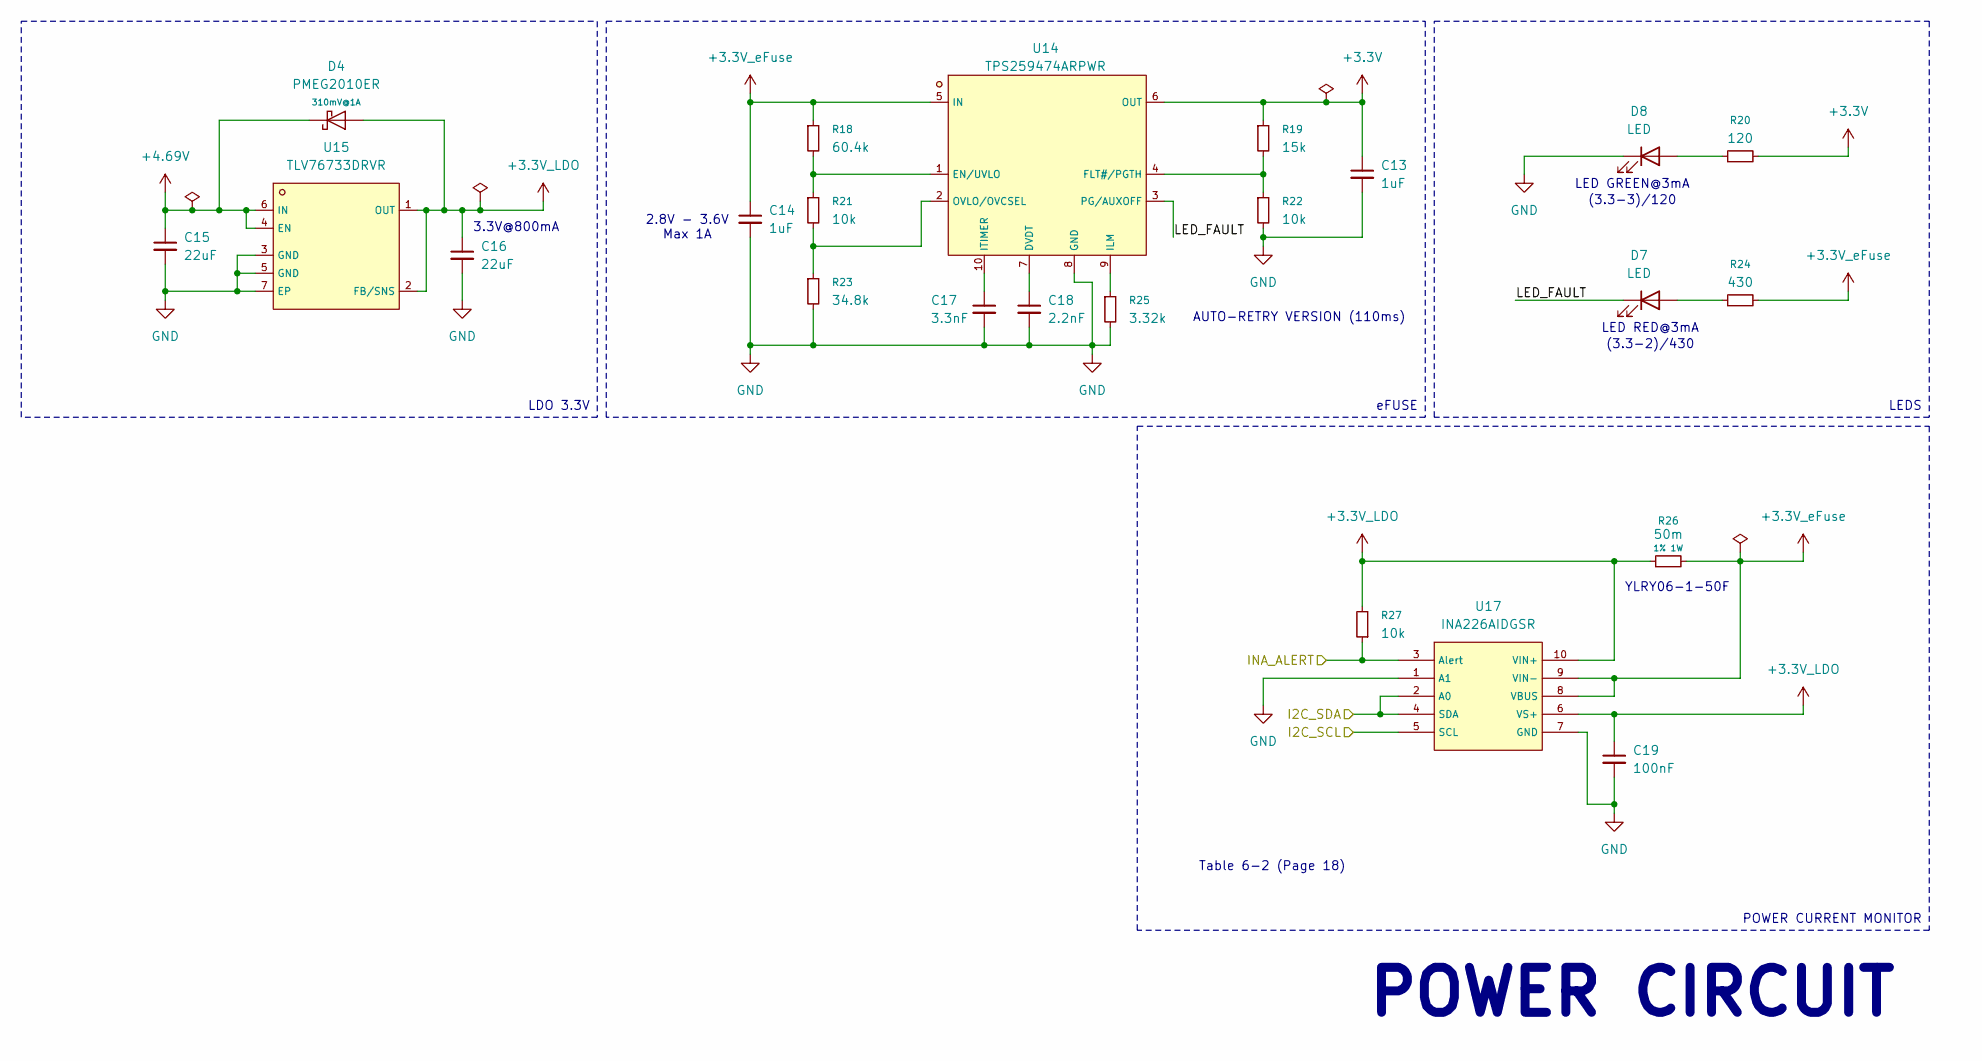
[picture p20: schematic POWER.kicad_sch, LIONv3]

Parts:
C13, C14: 1uF; C_0603_1608Metric; LCSC C15849
C15, C16: 22uF; C_0805_2012Metric; LCSC C45783
C17: 3.3nF; C_0402_1005Metric; LCSC C3881585
C18: 2.2nF; C_0402_1005Metric; LCSC C2987940
C19: 100nF; C_0402_1005Metric; LCSC C307331
D4: PMEG2010ER; Nexperia_CFP3_SOD-123W; Rating 310mV@1A; LCSC C82288
D7: LED; LED_0603_1608Metric; LCSC C965799
D8: LED; LED_0603_1608Metric; LCSC C965804
R18: 60.4k; R_0402_1005Metric; LCSC C2998058
R19: 15k; R_0402_1005Metric; LCSC C25756
R20: 120; R_0402_1005Metric; LCSC C2909389
R21, R22, R27: 10k; R_0402_1005Metric; LCSC C25744
R23: 34.8k; R_0402_1005Metric; LCSC C2076772
R24: 430; R_0402_1005Metric; LCSC C2909321
R25: 3.32k; R_0402_1005Metric; LCSC C2998161
R26: 50m; R1206; Tolerance 1%; Rating ${Tolerance} ${Rated_Power}; LCSC C20608719
U14: TPS259474ARPWR; VQFN-10_L2.0-W2.0-P0.45-TL; LCSC C3662807
U15: TLV76733DRVR; WSON-6_L2.0-W2.0-P0.65-TL-EP; LCSC C2848334
U17: INA226AIDGSR; MSOP-10_L3.0-W3.0-P0.50-LS5.0-BL; LCSC C49851

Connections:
+3.3V: C13.1, R19.1, R20.2, U14.6 (OUT); also elsewhere on the board
+3.3V_LDO: C16.1, C19.1, D4.2 (A), R26.1, R27.2, U15.1 (OUT), U15.2 (FB/SNS), U17.6 (VS+), U17.10 (VIN+); also elsewhere on the board
+3.3V_eFuse: C14.1, R18.1, R24.2, R26.2, U14.5 (IN), U17.8 (VBUS), U17.9 (VIN-)
+4.69V: C15.1, D4.1 (K), U15.4 (EN), U15.6 (IN); also elsewhere on the board
/I2C_SCL: U17.5 (SCL); also elsewhere on the board
/I2C_SDA: U17.2 (A0), U17.4 (SDA); also elsewhere on the board
/INA_ALERT: R27.1, U17.3 (Alert); also elsewhere on the board
/POWER/LED_FAULT: D7.1 (K), U14.3 (PG/AUXOFF)
GND: C13.2, C14.2, C15.2, C16.2, C17.2, C18.2, C19.2, D8.1 (K), R22.2, R23.2, R25.2, U14.8 (GND), U15.3 (GND), U15.5 (GND), U15.7 (EP), U17.1 (A1), U17.7 (GND); also elsewhere on the board
unnamed: D7.2 (A), R24.1
unnamed: D8.2 (A), R20.1
unnamed: C18.1, U14.7 (DVDT)
unnamed: R18.2, R21.1, U14.1 (EN/UVLO)
unnamed: R19.2, R22.1, U14.4 (FLT#/PGTH)
unnamed: R25.1, U14.9 (ILM)
unnamed: C17.1, U14.10 (ITIMER)
unnamed: R21.2, R23.1, U14.2 (OVLO/OVCSEL)

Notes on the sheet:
POWER CIRCUIT
3.3V@800mA
2.8V - 3.6V Max 1A
(3.3-3)/120
AUTO-RETRY VERSION (110ms)
LED GREEN@3mA
LED RED@3mA
YLRY06-1-50F
(3.3-2)/430
Table 6-2 (Page 18)
POWER CURRENT MONITOR
LEDS
LDO 3.3V
eFUSE

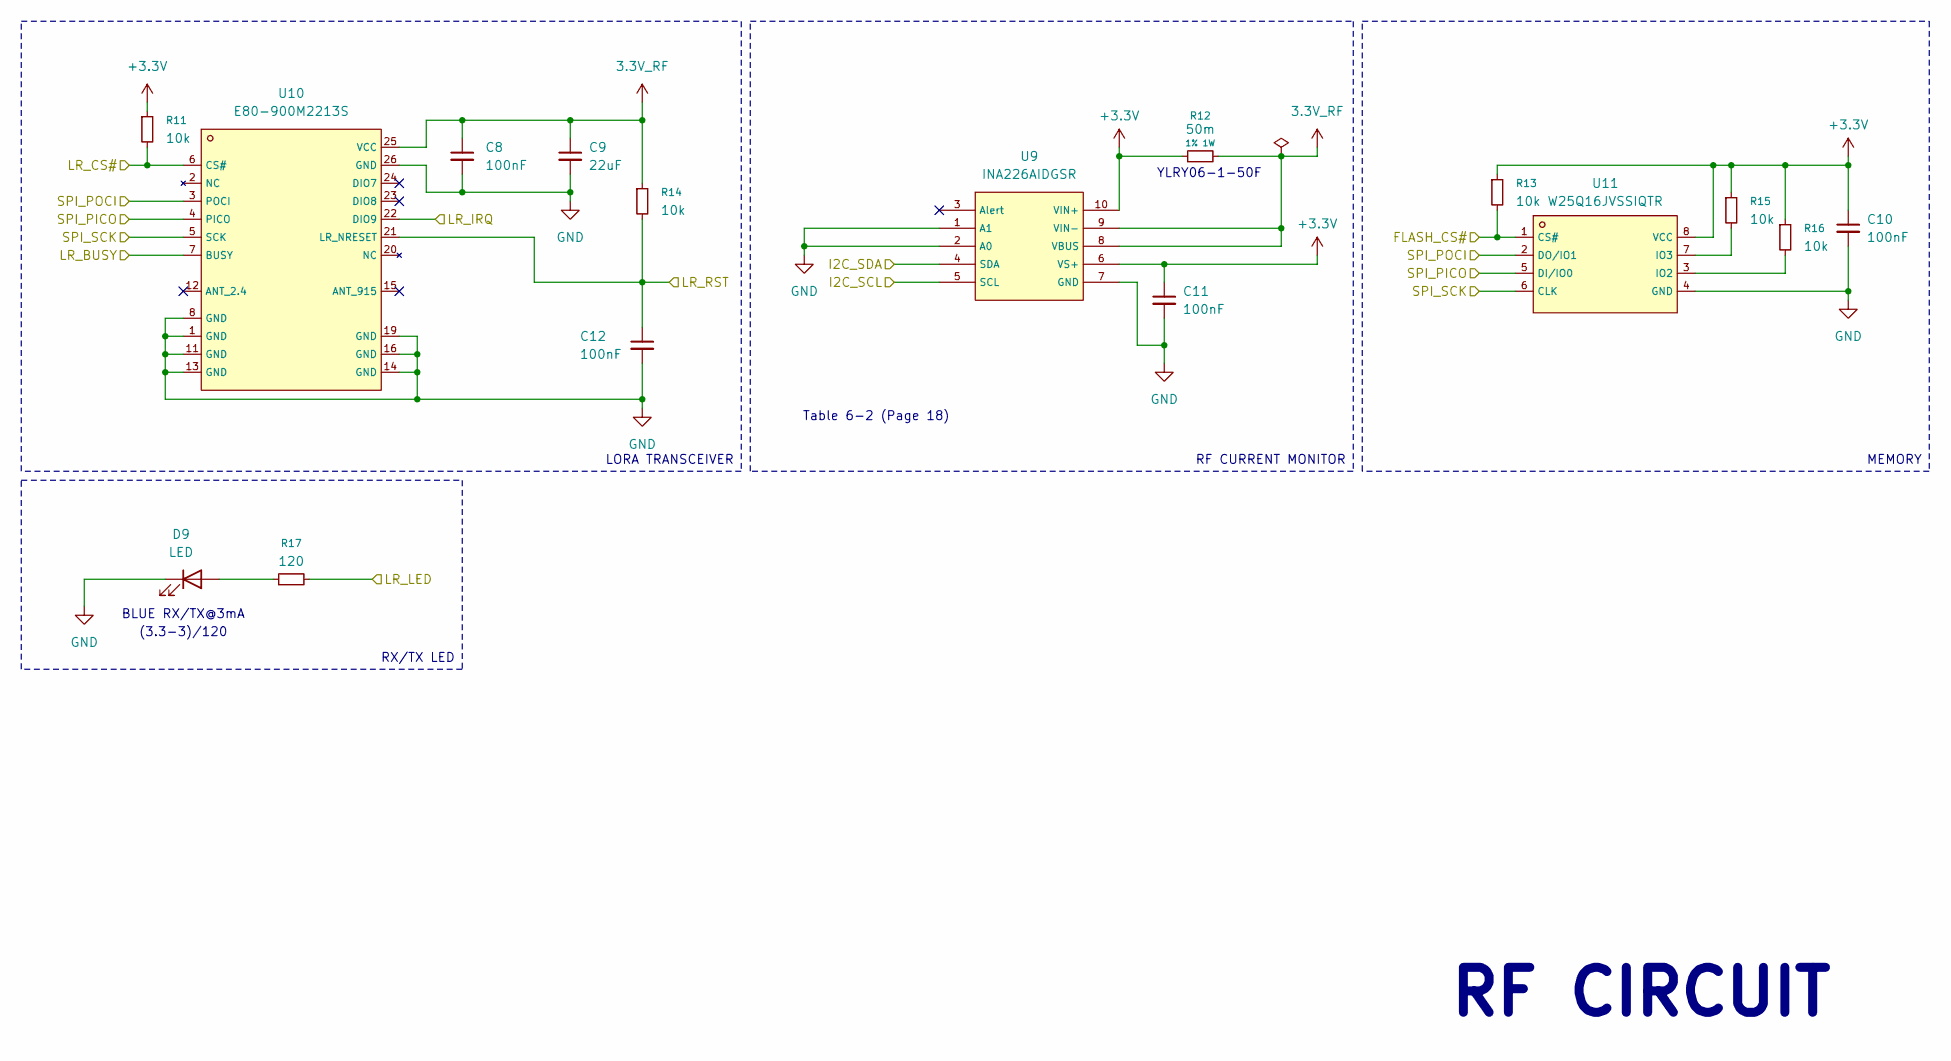
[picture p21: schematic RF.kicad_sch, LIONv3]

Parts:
C8, C10, C11, C12: 100nF; C_0402_1005Metric; LCSC C307331
C9: 22uF; C_0805_2012Metric; LCSC C45783
D9: LED; LED_0603_1608Metric; LCSC C965807
R11, R13, R14, R15, R16: 10k; R_0402_1005Metric; LCSC C25744
R12: 50m; R1206; Tolerance 1%; Rating ${Tolerance} ${Rated_Power}; LCSC C20608719
R17: 120; R_0402_1005Metric; LCSC C2909380
U9: INA226AIDGSR; MSOP-10_L3.0-W3.0-P0.50-LS5.0-BL; LCSC C49851
U10: E80-900M2213S; WIFIM-SMD_22P-L26.0-W16.0-P1.27-TL; LCSC C42464134
U11: W25Q16JVSSIQTR; SOIC-8_L5.3-W5.3-P1.27-LS8.0-BL; LCSC C131025

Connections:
3.3V_RF: C8.1, C9.1, R12.2, R14.1, U9.8 (VBUS), U9.9 (VIN-), U10.25 (VCC)
+3.3V: C10.1, C11.1, R11.1, R12.1, R13.1, R15.1, R16.1, U9.6 (VS+), U9.10 (VIN+), U11.8 (VCC); also elsewhere on the board
/FLASH_CS#: R13.2, U11.1 (CS#); also elsewhere on the board
/I2C_SCL: U9.5 (SCL); also elsewhere on the board
/I2C_SDA: U9.4 (SDA); also elsewhere on the board
/LR_BUSY: U10.7 (BUSY); also elsewhere on the board
/LR_CS#: R11.2, U10.6 (CS#); also elsewhere on the board
/LR_IRQ: U10.22 (DIO9); also elsewhere on the board
/LR_LED: R17.2; also elsewhere on the board
/LR_RST: C12.1, R14.2, U10.21 (LR_NRESET); also elsewhere on the board
/SPI_PICO: U10.4 (PICO), U11.5 (DI/IO0); also elsewhere on the board
/SPI_POCI: U10.3 (POCI), U11.2 (DO/IO1); also elsewhere on the board
/SPI_SCK: U10.5 (SCK), U11.6 (CLK); also elsewhere on the board
GND: C8.2, C9.2, C10.2, C11.2, C12.2, D9.1 (K), U9.1 (A1), U9.2 (A0), U9.7 (GND), U10.1 (GND), U10.8 (GND), U10.11 (GND), U10.13 (GND), U10.14 (GND), U10.16 (GND), U10.19 (GND), U10.26 (GND), U11.4 (GND); also elsewhere on the board
unnamed: D9.2 (A), R17.1
unnamed: R16.2, U11.3 (IO2)
unnamed: R15.2, U11.7 (IO3)

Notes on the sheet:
BLUE RX/TX@3mA
RF CIRCUIT
Table 6-2 (Page 18)
(3.3-3)/120
YLRY06-1-50F
MEMORY
RX/TX LED
RF CURRENT MONITOR
LORA TRANSCEIVER

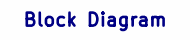
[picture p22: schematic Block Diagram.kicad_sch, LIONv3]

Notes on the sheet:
Block Diagram

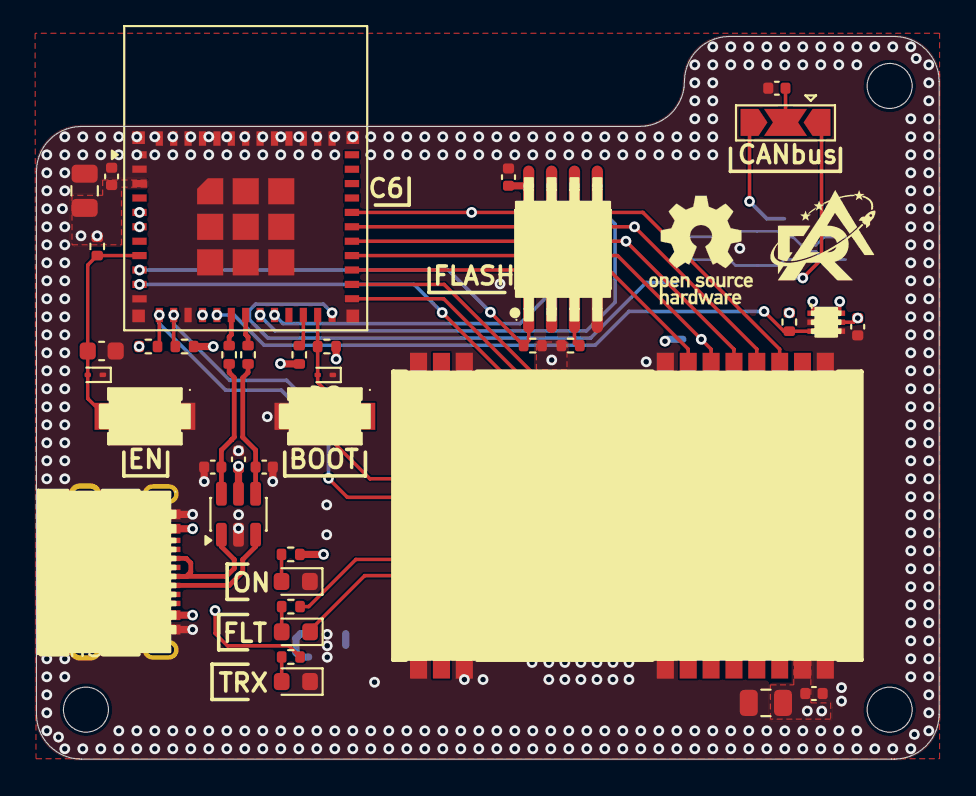
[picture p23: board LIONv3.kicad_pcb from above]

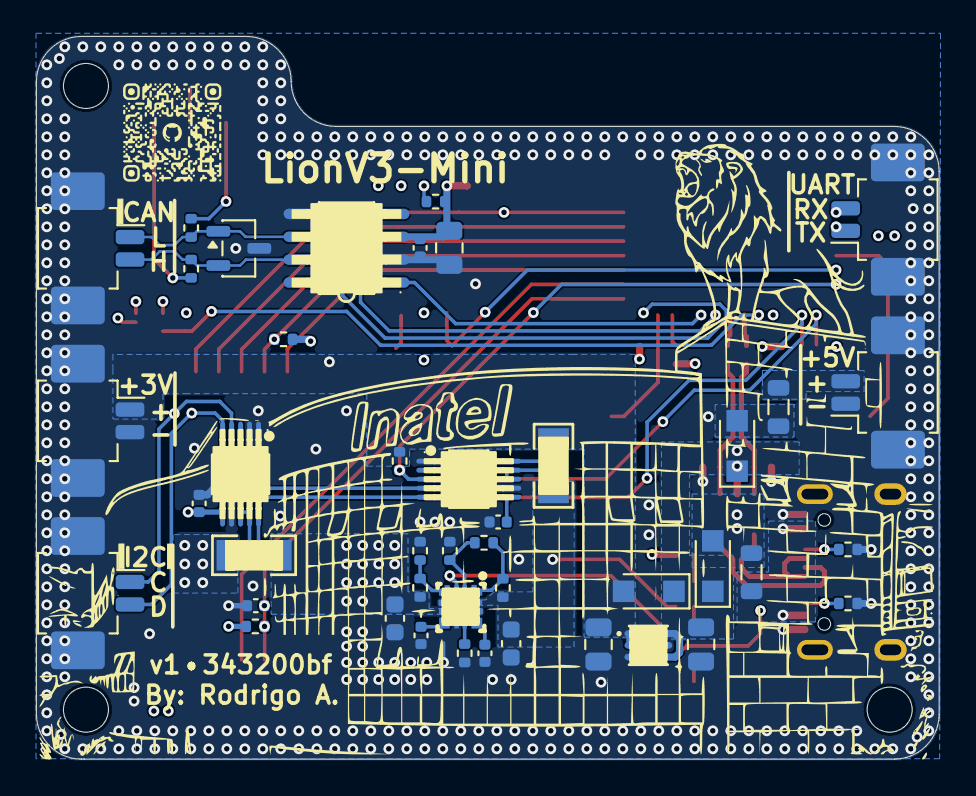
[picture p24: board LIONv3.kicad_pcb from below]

Board: 4 copper layers, 50.2 x 40.2 mm, 84 parts (43 on the bottom side), 56 nets.

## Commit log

2026-09-30 refactor(hardware): improve schematic
    [CANbus.kicad_sch, LIONv3.kicad_pcb, LIONv3.kicad_sch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]
2026-09-30 feat(hardware): adapt PCB layout to Mini version
    [LIONv3.kicad_pcb]
2026-10-01 feat(hardware): improve silkscreen positioning
    [LIONv3.kicad_pcb, LIONv3.kicad_sch, POWER.kicad_sch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]
2026-10-02 feat(hardware): finish LIONv3-Mini routing
    [LIONv3.kicad_pcb, LIONv3.kicad_sch]
2026-10-05 feat(hardware): finish LIONv3-Mini rev1.0
    [Block Diagram.kicad_sch, CANbus.kicad_sch, LIONv3.kicad_pcb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]
